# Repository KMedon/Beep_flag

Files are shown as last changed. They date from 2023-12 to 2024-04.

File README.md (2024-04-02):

# Football Referee Flags with LoRa Communication
# Overview
This repository houses my engineering project, a cutting-edge set of football referee flags designed with LoRa technology for seamless and effective wireless communication. Aimed at transforming the communication dynamics for referees, especially in lower leagues where advanced communication tools may not be readily available, this project seeks to enhance decision-making accuracy and efficiency on the field.

# Genesis
The inspiration behind this project was to bridge the communication gap faced by referees in lower-tier football leagues. These leagues often lack the resources for sophisticated communication devices, impacting the referees' ability to make quick and accurate decisions. By developing a reliable and easy-to-use set of referee flags with a receiver, this project aims to provide a cost-effective solution that elevates the quality of game officiating across all levels of play.

# Technology
Utilizing LoRa (Long Range) technology at the 868 MHz frequency enables dependable wireless communication over considerable distances. The core of this system is the RAK3172 module, powered by an STM32WLE5 microcontroller, chosen for its performance and reliability. The project was developed in STM32CubeIDE, incorporating the Sub-GHz PHY library for managing wireless communications efficiently.

# Mechanical Design and Testing
The project extends beyond software and communication technologies to include detailed mechanical design and rigorous testing. Files outlining the mechanical construction and assembly of both the flags and the receiver are provided, alongside results from tests designed to evaluate current consumption and the communication range, ensuring system efficiency and field readiness.

# PCB Design
A pivotal aspect of the project is the meticulously designed PCBs for the flag and receiver units. These designs prioritize low power consumption and effective LoRa communication, with durability and component reliability being key considerations to withstand the physical demands of football matches.





# Software
A standout feature of the software is the intuitive interaction between the referee flags and the receiver. When a referee presses the button on a flag, it triggers a buzzer on the receiver unit. This immediate audio feedback ensures that messages are conveyed promptly and unmistakably, supporting referees in maintaining focus on the game without distractions.




The software is crafted with attention to efficiency and responsiveness, ensuring seamless communication between devices. 

# Features
Long-range LoRa communication (868 MHz) tailored for referees in lower leagues
Custom PCB designs for flag and receiver, emphasizing efficiency and durability
In-depth mechanical designs with extensive durability and performance testing
Immediate audio feedback via receiver buzzer upon flag button press
Developed in STM32CubeIDE using the Sub-GHz PHY library

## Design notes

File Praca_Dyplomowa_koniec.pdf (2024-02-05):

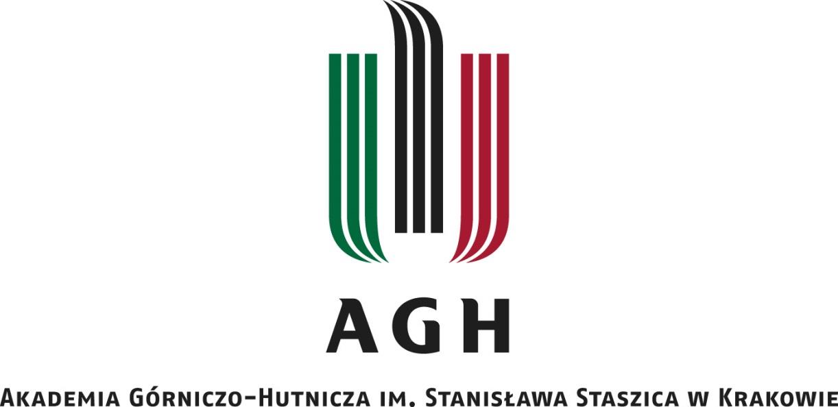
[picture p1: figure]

WYDZIAŁ INFORMATYKI, ELEKTRONIKI I TELEKOMUNIKACJI

INSTYTUT ELEKTRONIKI

PROJEKT DYPLOMOWY

## Elektroniczna flaga sędziowska

### Electronic referee flag

Autor: | Jakub Medoń
Kierunek studiów: | Elektronika i Telekomunikacja
Opiekun pracy: | dr inż. Łukasz Krzak

Kraków, 2024

## Spis treści

## 1. Wstęp

W dobie cyfryzacji, świat sportu przechodzi transformację, w której technologia zyskuje na

znaczeniu jako kluczowy element zapewniający sprawiedliwość i dynamikę rozgrywek.

Sędziowie sportowi pełnią kluczową rolę w pilnowaniu przestrzegania przepisów gry i

wymagane jest, aby podejmowane przez nich decyzje były szybkie i skuteczne. Komunikacja

pomiędzy członkami zespołu sędziowskiego jest niezbędna. Poprzez rozwój technologii

bezprzewodowej, sędzia piłkarski w trakcie spotkania ma do dyspozycji komunikację głosową

poprzez zestaw słuchawkowy, a także cichą komunikację za pomocą chorągiewki. Niniejsza

praca skupia się na projekcie oraz implementacji elektronicznej flagi sędziowskiej.

Motywacją do zrobienia tego projektu, była obserwacja, że sędziowie z niższych szczebli

rozgrywkowych nie stosują tego rodzaju komunikacji. Powodem tego jest zbyt wysoka cena

elektronicznych chorągiewek na rynku. Będąc świadomym jak dużą rolę odgrywa ten produkt

w podejmowaniu prawidłowych decyzji, postanowiono zaprojektować urządzenie, które będzie

spełniać tą samą funkcjonalność oraz będzie dostępne cenowo dla szerszego grona sędziów.

Celem pracy było zaprojektowanie i wykonanie prototypu elektronicznych flag

sędziowskich wraz z odbiornikiem, które komunikują się między sobą za pomocą technologii

LoRa. Głównym założeniem jest umożliwienie cichej i niezawodnej komunikacji w zespole

sędziowskim tak, aby po naciśnięciu przycisku na chorągiewce, sędzia główny otrzymywał

sygnał dźwiękowy bezpośrednio na swoje ramię.

Rozdział drugi przedstawia analizę rynku elektronicznych flag sędziowskich, ich

funkcjonalności oraz relację jakości do ceny. Następnie, w rozdziale trzecim, omówione zostały

technologie i narzędzia wykorzystane w projekcie, w tym technologia LoRa oraz

oprogramowanie wspomagające projektowanie i programowanie urządzeń.

W rozdziale czwartym szczegółowo opisano projekt płyty drukowanej (PCB), która stanowi

fundament dla elektronicznych komponentów opracowanego urządzenia, wraz z analizą celów

projektowych, metodologią opracowania schematów i rozmieszczenia elementów, a także

kryteriami doboru poszczególnych części. Następnie, rozdział piąty koncentruje się na procesie tworzenia oprogramowania, kluczowym dla funkcjonowania systemu, przedstawiając wybrane

biblioteki, sterowniki oraz implementację komunikacji bezprzewodowej.

W końcowej części pracy przedstawione zostały wyniki testów funkcjonalnych, zasięgu

oraz zużycia prądu, które posłużyły do wyciągnięcia wniosków i oceny wykonanego

prototypu. Całość zakończona jest podsumowaniem, które integruje wszystkie elementy

projektu, prezentując konkluzje i możliwe kierunki dalszego rozwoju.

## 2. Analiza istniejących rozwiązań

Opis ogólny

Współczesny rynek sprzętu sędziowskiego w sporcie charakteryzuje się ciągłym postępem

technologicznym, którego celem jest usprawnienie komunikacji na boisku oraz zwiększenie

precyzji podejmowanych decyzji. W ramach tego rozwoju, szczególne miejsce zajmują

elektroniczne flagi sędziowskie, które są kluczowym narzędziem w profesjonalnych

dyscyplinach sportowych takich jak piłka nożna i rugby. Te innowacyjne urządzenia zostały

zaprojektowane, aby zapewnić sędziom liniowym możliwość bezbłędnego i natychmiastowego

komunikowania się z sędzią głównym, nawet w najbardziej hałaśliwych i dynamicznych

warunkach meczowych.

Elektroniczne flagi sędziowskie wykorzystują różnorodne technologie komunikacyjne, w

tym systemy radiowe i dźwiękowe. Wśród dostępnych na rynku produktów wyróżniają się

modele, które oferują funkcje takie jak sygnalizacja dźwiękowa o różnych poziomach

głośności, wibracje, wskaźniki LED informujące o stanie naładowania baterii, ergonomiczny

kształt i odporność na warunki atmosferyczne.

Produkty na rynku różnią się pod względem specyfikacji, funkcjonalności i ceny, co

odzwierciedla różnorodne potrzeby użytkowników oraz dynamiczny rozwój. W tym rozdziale

przestawiona zostanie analiza najbardziej znaczących produktów na rynku.

Przegląd produktów

SignalBip Electronic Flags: To nowoczesne flagi sędziowskie charakteryzujące się

ergonomicznymi uchwytami, wykonane zostały z miękkiego materiału dla lepszego chwytu.

Zawierają również wskaźnik LED, który sygnalizuje stan naładowania baterii, a ich średni czas

ładowania wynosi godzinę, co jest akceptowalnym czasem umożliwiającym szybkie

przygotowanie sprzętu do użytku. System wykorzystuje pasmo częstotliwości od 863 do 870

MHz, co zapewnia niezawodność transmisji danych w warunkach typowych dla środowiska

stadionu piłkarskiego. SignalBip oferuje trzy poziomy głośności dźwięku i pięć poziomów

wibracji, co pozwala sędziemu dostosować urządzenie do własnych preferencji. W skład

zestawu wchodzą dwie flagi oraz opaska na ramię z sygnałem wibracyjnym i dźwiękowym dla

sędziego głównego [1].

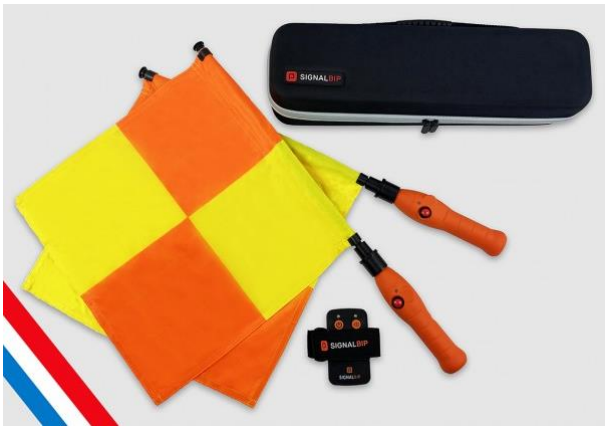
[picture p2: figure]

Rys. 1 Zestaw flag SignalBip [1]

ErvoCom Referee Flags: Używane w najwyższych ligach piłkarskich, w tym w Premier

League, Bundeslidze i podczas meczów FIFA. Flagi ErvoCom wyróżniają się zaawansowaną

technologią kodowania, która eliminuje ryzyko zakłóceń. Posiadają gumowane uchwyty, które

dobrze sprawdzają się na mokre i wilgotne warunki, a także szybko rozpoznawalne przyciski

na przedniej i tylnej części flagi. Flaga ErvoCom wibruje, aby potwierdzić wysłanie sygnału

do sędziego, posiada różne tryby wibracji dla pierwszego i drugiego asystenta sędziego.

Ponadto, urządzenie oferuje regulowaną głośność dźwięku, a jednostka odbiorcza sędziego

może być programowana do powiadamiania dźwiękiem, wibracją lub oboma bodźcami

jednocześnie [2].

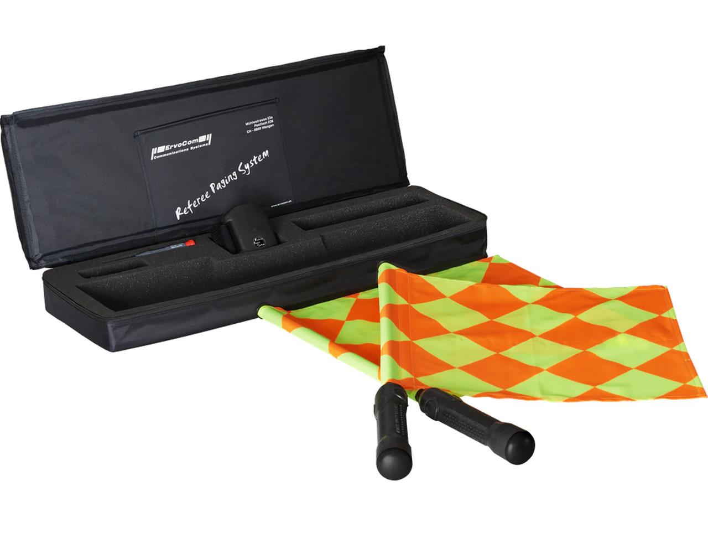
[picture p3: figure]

Rys. 2 Zestaw flag ErvoCom [2]

Analiza techniczna

W tab. 1 porównano specyfikacje techniczne dwóch czołowych modeli elektronicznych flag

sędziowskich: SignalBip Electronic Flags i ErvoCom Referee Flags.

Tab. 1 Porównanie specyfikacji technicznych wybranych produktów

Model | SignalBip Electronic Flags | ErvoCom Referee Flags
Cena | €579.80 | €729.95
Częstotliwość (MHz) | 863-870 | Nie ustalono
Komunikacja | Nie podano | Dwukierunkowa z potwierdzeniem odbioru
Maksymalna liczba flag | 5 flag na system | 10 flag na system
Funkcje powiadomień | Dźwięk (3 poziomy), wibracje (5 poziomów) | Dźwięk (3 poziomy), wibracje (5 poziomów)
Wodoodporność | Tak | Tak
Tryb oszczędzania energii | Tak | Tak
Wskaźnik baterii | LED | LED, Wibracja
Uchwyt | Uchwyty ergonomiczne | Uchwyty ergonomiczne
Materiał | Soft-touch | Nie podano

W obu przypadkach, produkty spełniają podobną funkcję – umożliwiają efektywną

komunikację między sędziami. Wybór między nimi zależy od indywidualnych potrzeb i

budżetu, przy czym ErvoCom oferuje większą skalowalność i zaawansowaną komunikację,

podczas gdy SignalBip jest bardziej dostępny cenowo.

## 3. Zastosowane technologie i oprogramowania

## 3.1. Technologia LoRa

Wprowadzenie

LoRa (ang. Long Range) to technologia komunikacji radiowej oferująca relatywnie daleki

zasięg, która wykorzystuje modulację rozpraszania widma opartą na CSS (ang. Chirp Spread

Spectrum). Umożliwia ona transmisję radiową na dużych dystansach przy jednoczesnym

niskim zużyciu energii. Dzięki temu, urządzenia IoT (ang. Internet of Things) w niektórych

aplikacjach mogą komunikować się przez lata bez konieczności wymiany baterii, co otwiera

nowe możliwości w dziedzinie zdalnego monitorowania i kontrolowania.

Historia LoRa sięga początków XXI wieku, kiedy to francuska firma Cycleo z Grenoble

opracowała i opatentowała tę technikę. Została ona później nabyta i spopularyzowana przez

korporację Semtech, przez co szybko stała się kluczowym elementem ekosystemu IoT. Dzięki

współpracy z założycielami Cycleo, Semtech dopracował technologię i wypuścił na rynek

dedykowane chipy, które znalazły zastosowanie w milionach urządzeń na całym świecie [3].

LoRa wykorzystywana jest w wielu dziedzinach, od inteligentnych miast, które monitorują

jakość powietrza, ruch uliczny i zarządzanie oświetleniem, po zaawansowane rolnictwo, gdzie

wykorzystuje się czujniki do optymalizacji zużycia wody i monitorowania warunków upraw.

Jest również kluczowa w zarządzaniu zasobami, takimi jak śledzenie przesyłek w logistyce i

monitorowanie stanu infrastruktury. Dzięki swojej adaptowalności, LoRa jest używana także

w inteligentnym zarządzaniu energią i w aplikacjach monitorowania dzikiej przyrody [4].

Zaletą tej technologii jest odporność na interferencje i zdolność do penetracji przeszkód, co

czyni ją idealną do zastosowań miejskich. Wadami są ograniczona przepustowość i wyższe

opóźnienia w transmisji danych, co sprawia, że nie nadaje się do aplikacji wymagających

szybkiego przesyłania dużej ilości danych, takich jak transmisja wideo czy komunikacja

głosowa w czasie rzeczywistym [4].

Modulacja

Technologia LoRa odnosi się do zasad twierdzenia Shannona-Hartleya, podkreślając, jak

krytyczne jest zarządzanie pasmem i stosunkiem sygnału do szumu (SNR ang. Signal-to-Noise

Ratio) dla maksymalizacji przepustowości kanału komunikacyjnego. W praktyce, LoRa

dostosowuje te parametry, aby umożliwić niezawodną transmisję danych w środowisku o

ograniczonej szerokości pasma oraz zmiennym SNR, co jest istotne dla zachowania spójności

i jakości komunikacji w systemie LoRa [5].

Kluczową techniką modulacji stosowaną w LoRa jest CSS, która jest specyficzną odmianą

modulacji częstotliwości sygnału radiowego. Chirp (ang. Compressed High Intensity Radar

Pulse) to sygnał, którego częstotliwość zmienia się liniowo w czasie, może rosnąć lub maleć.

Chirp pełni funkcję nośnika danych, co przekłada się na dobrą czułość odbiornika i odporność

na zakłócenia [5].

Kluczowe parametry modulacji:

1. Szerokość pasma (ang. Modulation Bandwidth): W LoRa, BW waha się od 125 kHz

do 500 kHz, co wpływa na szybkość transmisji danych i zasięg. Mniejsza szerokość

pasma pozwala na większy zasięg przy niższej szybkości.

2. Czynnik rozpraszania (ang. Spread Factor): SF w LoRa określa stopień rozpraszania

widma sygnału, z wartościami od 7 do 12. Wyższe wartości SF umożliwiają większy

zasięg transmisji, lecz przy niższej szybkości.

3. Wskaźnik kodowania (ang. Code Rate): CR odnosi się do redundantności w

kodowaniu FEC, pomagając korygować błędy transmisji. Wyższa redundancja

zwiększa niezawodność, ale zmniejsza przepustowość. Możliwe są 4 wartości tego

parametru: 4/5, 4/6, 4/7, 4/8 [6].

Szybkość bitową łącza można wyliczyć ze wzoru:

Rb = SF ∗

CR ∗ BW [Hz]
2

SF

Pasma częstotliwości

LoRa wykorzystuje pasma częstotliwości ISM (ang. Industrial, Scientific, Medical), które

są specyficzne dla danego regionu i nie wymagają licencji, na przykład 434/868 MHz w

Europie i 915 MHz w Ameryce Północnej. Wybór odpowiedniego pasma częstotliwości jest

kluczowy dla zapewnienia efektywnej komunikacji i długiego zasięgu, a także minimalizacji

zakłóceń i interferencji.

Tab. 2 Zakres pasma częstotliwości pracy LoRa w zależności od regionu

Region | Częstotliwość (MHz)
Europa | EU863-870, EU433
Chiny | CN470
Ameryka Północna | US915
Azja | AS923, AS920
Australia | AU915
Korea | KR920
Indie | IN865

Parametry jakości sygnału

Stosunek Sygnału do Szumu (SNR) w LoRa to kluczowy wskaźnik, który mierzy relację

między mocą odbieranego sygnału, a poziomem szumu na wejściu odbiornika radiowego. Jest

to krytyczna miara dla oceny jakości sygnału w systemach komunikacji bezprzewodowej.

Wysoki SNR wskazuje, że sygnał jest znacznie silniejszy niż szum, co prowadzi do mniejszej

liczby błędów i ponownych transmisji. W środowiskach o wysokim poziomie zakłóceń,

utrzymanie odpowiedniego SNR może być wyzwaniem, jednak LoRa jest zaprojektowana do

skutecznego działania nawet w trudnych warunkach, gdzie wartość parametru może być niska.

SNR ma bezpośredni wpływ na zasięg sygnału – wyższe wartości pozwalają na komunikację

na większe odległości i zapewniają lepszą jakość sygnału. W LoRa stosuje się różne techniki

do poprawy SNR, w tym wybór odpowiednich pasm częstotliwości, regulację mocy nadawania

i optymalizację anten, co ma na celu zwiększenie mocy sygnału lub zmniejszenie wpływu

szumu. Również parametry modulacji, takie jak szerokość pasma i czynnik rozpraszania, są

dostosowywane w zależności od warunków transmisji, tak aby zoptymalizować wartość parametru. Typowe wartości SNR dla LoRa mieszczą się w zakresie od -20dB do +10dB.

Wartość bliższa +10dB oznacza, że odbierany sygnał jest mniej zakłócony [7].

Wskaźnik Siły Odbieranego Sygnału (RSSI, ang. Received Signal Strength Indication)

jest niezwykle ważny dla oceny jakości i efektywności komunikacji w sieciach

bezprzewodowych. W technologii LoRa, RSSI mierzy rzeczywistą moc sygnału odbieranego

przez urządzenie i jest wyrażony w decybel-miliwatach (dBm). Wartości RSSI dają

bezpośrednią informację o sile sygnału w danej lokalizacji, co jest kluczowe dla ustalenia

zasięgu i niezawodności sieci LoRa. W środowiskach o zmiennym poziomie zakłóceń, wysokie

wartości RSSI wskazują na silny sygnał, co przekłada się na stabilniejszą transmisję danych.

W LoRa, monitoring i optymalizacja RSSI są niezbędne do zarządzania siecią, ponieważ

pozwalają na dostosowanie ustawień, takich jak czynnik rozpraszania i szerokość pasma, do

warunków środowiskowych. Optymalizacja RSSI jest istotna dla zapewnienia efektywnej

komunikacji i minimalizacji zakłóceń, co ma bezpośredni wpływ na jakość i skuteczność

systemu LoRa. Typowe wartości RSSI dla LoRa mieszczą się w zakresie od -120dBm do -

30dBm. Wartość bliższa -30dBm oznacza, że odebrany sygnał jest silniejszy [7].

## 3.2. Wykorzystane oprogramowania i narzędzia

KiCAD

KiCAD został wykorzystany do zaprojektowania schematów elektronicznych i płytek

drukowanych (PCB, ang. Printed Circuit Board) dla systemu elektronicznych flag

sędziowskich. Jako zaawansowane, darmowe i otwarte oprogramowanie CAD, KiCAD

umożliwił precyzyjne zaplanowanie układów elektronicznych, co było niezbędne dla

zapewnienia efektywnej komunikacji i stabilności systemu.

Dzięki KiCAD możliwe było tworzenie szczegółowych schematów elektronicznych, co

ułatwiło identyfikację potencjalnych problemów projektowych na wczesnym etapie. W fazie

projektowania płytek drukowanych, KiCAD zapewnił elastyczne narzędzie do efektywnego

rozmieszczania komponentów i trasowania połączeń. Jego interfejs użytkownika i bogate

biblioteki komponentów znacząco przyspieszyły proces projektowania.

Zastosowano również funkcje kontroli błędów i narzędzia do wizualizacji 3D, co pozwoliło

na dokładne sprawdzenie projektu przed przystąpieniem do fazy produkcyjnej. Pozwoliło to

zminimalizować ryzyko popełnienia kosztownych błędów i umożliwiło optymalizację projektu

pod względem wydajności oraz kosztów produkcji

STM32CubeIDE

STM32CubeIDE, jako zintegrowane środowisko programistyczne, odegrało kluczową rolę

w rozwoju oprogramowania dla projektu. To narzędzie umożliwiło skuteczne programowanie

i debugowanie oprogramowania sterującego modułami RAK3172. Wyposażone w

zaawansowane funkcje wspierające różne języki programowania i zintegrowane narzędzia do

debugowania, STM32CubeIDE znacząco przyczyniło się do efektywnego tworzenia systemu.

Dzięki możliwości dokładnego śledzenia działania oprogramowania, STM32CubeIDE

pozwoliło na szybką identyfikację i rozwiązywanie problemów, co zwiększyło niezawodność i

wydajność finalnego produktu. Narzędzie to okazało się być nieocenionym elementem w

procesie opracowywania oprogramowania do systemu elektronicznych flag sędziowskich.

GPS Fields Area Measure

W ramach przeprowadzanych badań nad zasięgiem komunikacji LoRa z wykorzystaniem

modułów RAK3172, skorzystano z aplikacji mobilnej "GPS Fields Area Measure" do

dokładnego ustalenia odległości między urządzeniami. Aplikacja ta, wykorzystując system

GPS, pozwoliła na precyzyjne zmierzenie i zarejestrowanie odległości pomiędzy

poszczególnymi punktami testowymi.

Testy przeprowadzono na otwartej przestrzeni, gdzie dokładne wyznaczenie odległości

między modułami było kluczowe dla wiarygodności pomiarów zasięgu. "GPS Fields Area

Measure" umożliwiła łatwe i szybkie mierzenie odległości, co znacząco usprawniło proces

testowania. Dzięki tej aplikacji efektywnie udokumentowano wszystkie wykonane pomiary.

STLink-V3MINIE

Programator STLink-V3Minie został użyty do zaprogramowania modułów RAK3172 w

projekcie. Dzięki złączu SWD (ang. Serial Wire Debug), programowanie modułów przeprowadzono w sposób efektywny, co było kluczowe dla prawidłowego działania systemu

LoRa. Programator ten, ze względu na swoją wydajność i niezawodność, był idealnym

narzędziem do tego zadania.

Dodatkowo, wykorzystanie interfejsu UART (ang. Universal Asynchronous Receiver and

Transmitter) w STLink-V3Mini umożliwiło śledzenie komunikacji między modułami. Dzięki

temu można było monitorować i diagnozować działanie systemu w czasie rzeczywistym, co

znacząco ułatwiło proces debugowania i testowania. Ta integracja narzędzi programistycznych

była istotna dla zapewnienia wysokiej jakości i stabilności finalnego produktu.

Rys. 3 STLINK-V3MINIE [8]

Lutownica Reball 72W

W projekcie wykorzystano lutownicę model Reball 72W, która odegrała kluczową rolę w

montażu i naprawie komponentów elektronicznych. Dzięki jej wysokiej mocy i precyzji,

możliwe było dokładne i efektywne łączenie elementów układów elektronicznych. Użycie tego

modelu lutownicy zapewniło nie tylko wysoką jakość lutowanych połączeń, ale również

przyczyniło się do zwiększenia niezawodności i funkcjonalności całego systemu. Umiejętne wykorzystanie lutownicy Reball 72W miało istotny wpływ na skuteczność procesu montażu

modułów oraz innych składników elektronicznych w ramach projektu.

## 3.3. Wybór sprzętu i komponentów

Moduł RAK3172

Moduł RAK3172 WisDuo, oparty na chipie STM32WLE5CC, został wykorzystany w

projekcie jako urządzenie transmisyjno-odbiorcze o zredukowanym zużyciu energii. Ten

moduł oferuje łatwe w użyciu, kompaktowe i energooszczędne rozwiązanie dla aplikacji

bezprzewodowej transmisji danych. Dodatkowo, wspiera komunikację LoRa P2P (ang. Point-

to-Point), co pozwoliło na szybką implementację spersonalizowanej sieci LoRa.

RAK3172 charakteryzuje się dalekim zasięgiem transmisji, przekraczającym 15 km przy

optymalnej antenie oraz wydajnym procesorem ARM Cortex-M4 32-bit. Posiada 256 KB

pamięci flash z ECC (ang. Error Checking and Correction) i 64 KB pamięci RAM (ang.

Random-access memory). Jego ultra-niskie zużycie energii, wynoszące zaledwie 1.69 µA w

trybie uśpienia, czyni go idealnym do zastosowań zasilanych bateryjnie [9].

Małe rozmiary modułu RAK3172 (15x15.5 mm) były kluczowe dla jego zastosowania w

projekcie, ponieważ umożliwiły łatwe zintegrowanie go z obudową chorągiewki, nie

ograniczając jej funkcjonalności ani estetyki. Wybór tego modułu przyczynił się do

efektywności i elastyczności całego systemu, co było niezbędne do realizacji celów projektu.

Antena

W projekcie wykorzystano antenę TI.08.C.0111 firmy Taoglas, przeznaczoną do pasma ISM

868 MHz, co jest istotne dla aplikacji LoRa. Zakres temperatury pracy anteny wynosił od -40°C

do 85°C, co wskazuje na jej odporność na różnorodne warunki środowiskowe i umożliwia jej

wykorzystanie w szerokim zakresie aplikacji [10].

Wybór anteny TI.08.C.0111 był podyktowany potrzebą zapewnienia optymalnego zasięgu i

jakości sygnału w systemie LoRa, przy jednoczesnym zachowaniu kompaktowych wymiarów

i niskiego profilu, co miało kluczowe znaczenie dla integracji anteny z projektem.

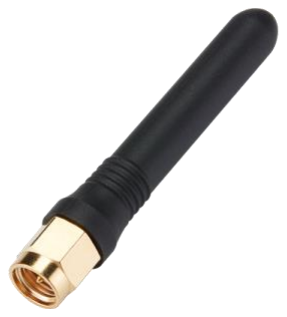
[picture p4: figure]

Rys. 4 Antena TI.08.C.0111 [10]

Rękojeść chorągiewki

W projekcie wykorzystano ergonomiczne rękojeści firmy SignalBip. Rękojeści wyposażono

w przycisk, który jest kluczowy dla funkcjonalności projektu. Posiada również specjalne

miejsce na zamontowanie płytki PCB, co umożliwiło integrację bez konieczności

wprowadzania zmian projektowych. Istotną modyfikacją była adaptacja wewnętrznej struktury

chorągiewki w celu umieszczenia specjalnego koszyczka na dwie baterie typu AAA.

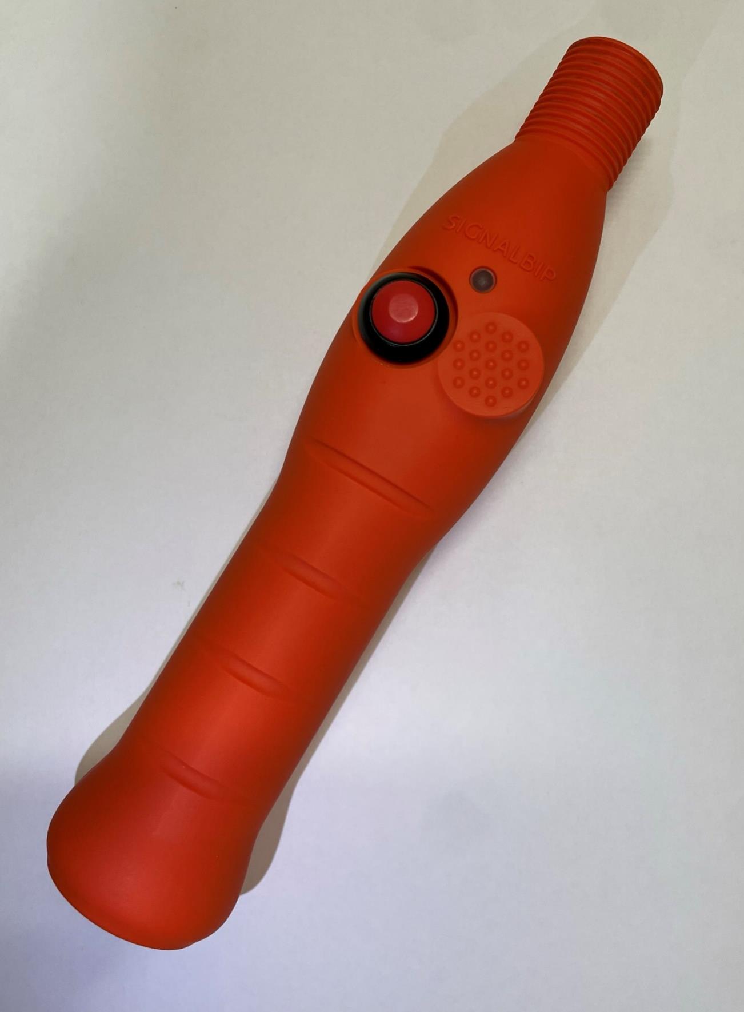
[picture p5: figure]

Rys. 5 Rękojeść chorągiewki sędziego asystenta

Obudowa odbiornika

W ramach projektu odbiornika na ramię sędziego, wybrano obudowę Maszczyk KM-79A

ABS o wymiarach 101 x 81 x 31 mm. Jest to dwuczęściowa, uniwersalna obudowa wykonana

z materiału ABS (ang. Acrylonitrile Butadiene Styrene), która charakteryzuje się wysoką

trwałością oraz odpornością na różnorodne warunki eksploatacyjne.

Kluczowym czynnikiem, który przesądził o wyborze tej obudowy jest jej funkcjonalność.

Przy wymiarach zewnętrznych 101 x 81 x 31 mm, obudowa oferuje wystarczającą przestrzeń

do umieszczenia niezbędnych komponentów elektronicznych. Obudowa jest łączona za

pomocą śrubek, co ułatwia montaż i demontaż, umożliwiając łatwy dostęp do peryferii systemu

odbiornika. Wspomniany dostęp jest również korzystny z punktu widzenia stabilności, co jest

istotne w kontekście potencjalnych przyszłych modyfikacji projektu [11].

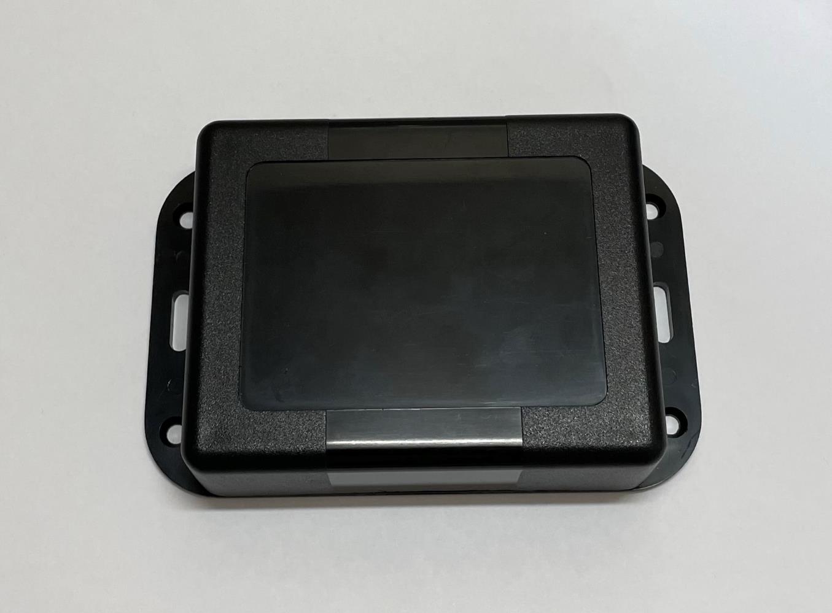
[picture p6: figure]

Rys. 6 Obudowa odbiornika sędziego głównego

## 4. Opis projektu PCB

## 4.1. Wstęp oraz cel projektu

W ramach pracy inżynierskiej, jednym z kluczowych zadań było zaprojektowanie

dedykowanych płytek drukowanych (PCB) dla nadajnika i odbiornika. Celem projektu PCB

dla nadajnika było osiągnięcie kompatybilności z rękojeścią, tak aby płytka mogła być łatwo

zintegrowana w jej wnętrzu. Istotnym wymaganiem było także zapewnienie możliwości

podłączenia przewodów do przycisku umieszczonego w rękojeści. W przypadku PCB

odbiornika, głównym celem było dopasowanie do jego specyficznej obudowy oraz

zaimplementowanie buzzer'a jako elementu sygnalizacyjnego.

Projektowanie PCB zostało przeprowadzone przy użyciu KiCAD, co umożliwiło

precyzyjne zaplanowanie układów elektronicznych, rozmieszczenie komponentów oraz

trasowanie ścieżek. KiCAD, jako zaawansowane oprogramowanie do projektowania PCB,

zapewniło niezbędne narzędzia do stworzenia efektywnych i niezawodnych rozwiązań,

spełniających wszystkie postawione wymagania projektowe.

## 4.2. Projekt nadajnika: schemat i funkcje elementów

Przegląd ogólny

Schemat przedstawia układ elektroniczny nadajnika, systemu elektronicznych flag

sędziowskich. Skupia się wokół modułu RAK3172, który połączony jest z różnymi peryferiami

i interfejsami. Układ zasilono napięciem 3V, co jest standardowe dla wielu mikrokontrolerów

o niskim zużyciu energii. Umieszczono także elementy do komunikacji szeregowej, wskaźniki

LED oraz przyciski do resetowania i wyboru trybu bootowania.

Opis użytych komponentów

- Moduł: Szczegółowy opis Modułu RAK3172 został wykonany w rozdziale 3.3.
- Kondensatory filtrujące (C1, C3, C8): Są to kondensatory odsprzęgające, które

stabilizują napięcie zasilania, redukując szumy i zapewniając oczyszczone zasilanie dla

obwodów cyfrowych i radiowych.

- Diody LED (D2, D3): Dwie diody LED oznaczone jako GREEN I RED, zostały

wykorzystane jako wskaźniki statusu, sygnalizujące różne stany pracy układu.

- Przyciski (RST, BOOT): Przyciski służące do resetowania modułu oraz do wejścia w

tryb bootloadera.

- Złącze (J5): Interfejs STDC14 umożliwił zaprogramowanie modułu.Jest kompatybilny

z programatorem STLink-v3minie. Piny SWDIO i SWCLK zostały podłączone do

odpowiednich pinów modułu. Komunikacja UART również została zrealizowana

poprzez podłączenie linii TX i RX między złączem, a modułem. Ważnym aspektem

było podłączenie linii VCC, które umożliwia debugerowi detekcję poziomu napięcia

układu. W pierwotnym projekcie pominięto podłączenie pinu RST ze złącza STDC14

do pinu resetu modułu. Brak tego połączenia uniemożliwiał wykorzystanie

zewnętrznego resetowania modułu za pomocą debugera, co jest kluczowe podczas

procesu programowania. Ta pomyłka została zidentyfikowana i poprawiona w

późniejszej fazie projektu.

- Rezystory: Rezystory R1/R2 pełnią funkcje ograniczenia prądu dla diod LED, wartości

rezystancji wyliczono za pomocą prawa Ohma. Element R3 jest rezystorem

podciągającym (ang. Pull-up Resistor), który utrzymuje pin resetu w stanie wysokim,

co zapobiega przypadkowemu resetowaniu urządzenia. Rezystory R4, R5, R7 i R8 to

elementy zabezpieczające przed odbiciami sygnałów (ang. Bouncing) i zakłóceniami

elektromagnetycznymi. Element R6 zapewnia utrzymanie stanu niskiego na pinie PA1,

który jest aktywnie sterowany.

- Punkt testowy (ang. TestPoint): Miejsce na schemacie, które umożliwia łatwe

przylutowanie przewodów od przycisku.

- Zasilanie: Układ został zasilony napięciem 3V poprzez dwie baterie AAA.

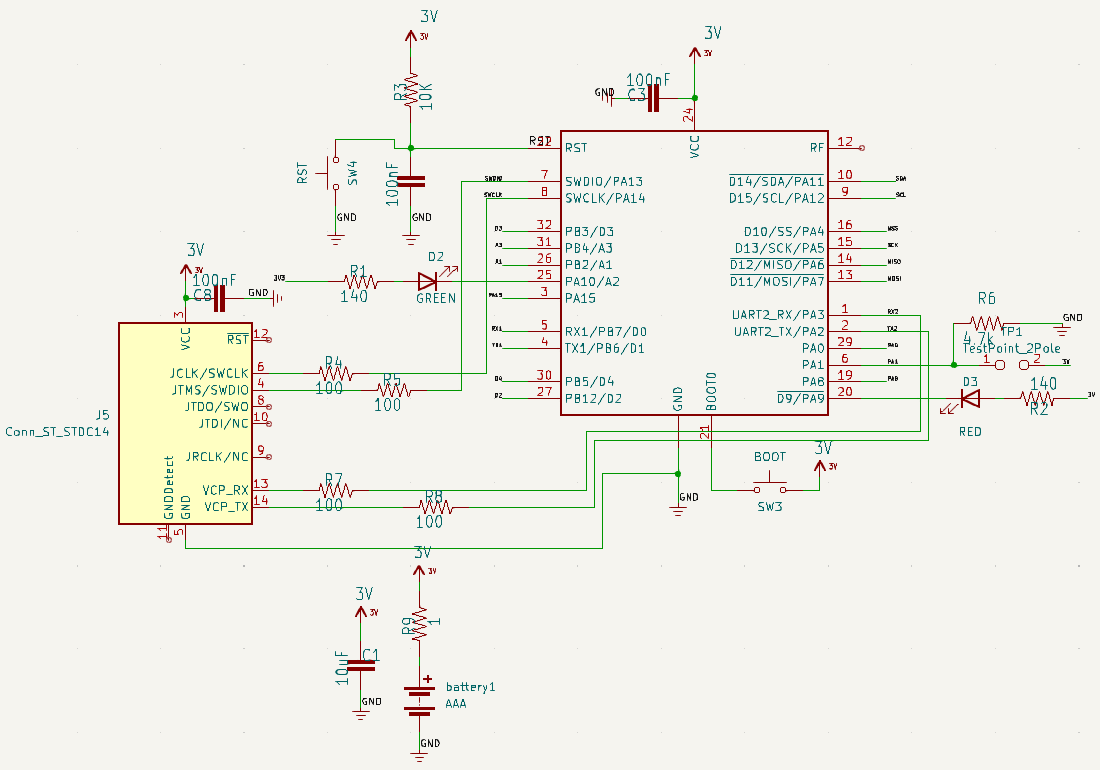
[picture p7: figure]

Rys. 7 Schemat elektroniczny nadajnika wykonany w programie KiCAD

Layout PCB

Projekt layoutu PCB dla nadajnika został dokładnie opracowany, aby spełnić wymagania

techniczne i ergonomiczne. Przyjęto ścieżki o szerokości 0.4 mm dla linii zasilających, co

zapewniało odpowiedni przekrój dla wymaganego prądu, natomiast ścieżki o szerokości 0.2

mm były przeznaczone do standardowych połączeń sygnałowych. Takie różnicowanie

szerokości ścieżek było istotne dla zachowania optymalnej pracy układu i minimalizacji

potencjalnych zakłóceń.

Moduł został strategicznie rozmieszczony po prawej stronie płytki, co wynikało z

konstrukcji rękojeści chorągiewki oraz potrzeby umieszczenia anteny w taki sposób, by była

skierowana ku górze chorągiewki. Taka lokalizacja modułu umożliwiała także efektywne

wykorzystanie przestrzeni na PCB.

Piny zasilania zostały umiejscowione po lewej stronie PCB, co odzwierciedlało położenie

koszyka z bateriami na dole chorągiewki. To rozwiązanie zapewniało skuteczny przepływ

energii od źródła zasilania do kluczowych komponentów układu.

Centralne położenie zielonej diody LED było uwarunkowane konstrukcją rękojeści

chorągiewki. Posiada ona tunel wizyjny, który przepuszcza światło zapalonej diody. Dzięki

temu, sygnalizacja pracy urządzenia jest klarowna i łatwo zauważalna przez użytkownika.

Ponadto, płytka posiada otwór montażowy o średnicy 2 mm, co umożliwiło solidne

przymocowanie PCB wewnątrz chorągiewki. Rozmiar PCB narzucał ograniczenia, które

wymagały racjonalnego wykorzystania dostępnej przestrzeni, szczególnie przy umieszczaniu

elementów i planowaniu ścieżek.

Na spodniej stronie PCB wykonano poligon masy, co jest standardową praktyką mającą na

celu poprawę odprowadzania ciepła oraz ochronę przed zakłóceniami elektromagnetycznymi.

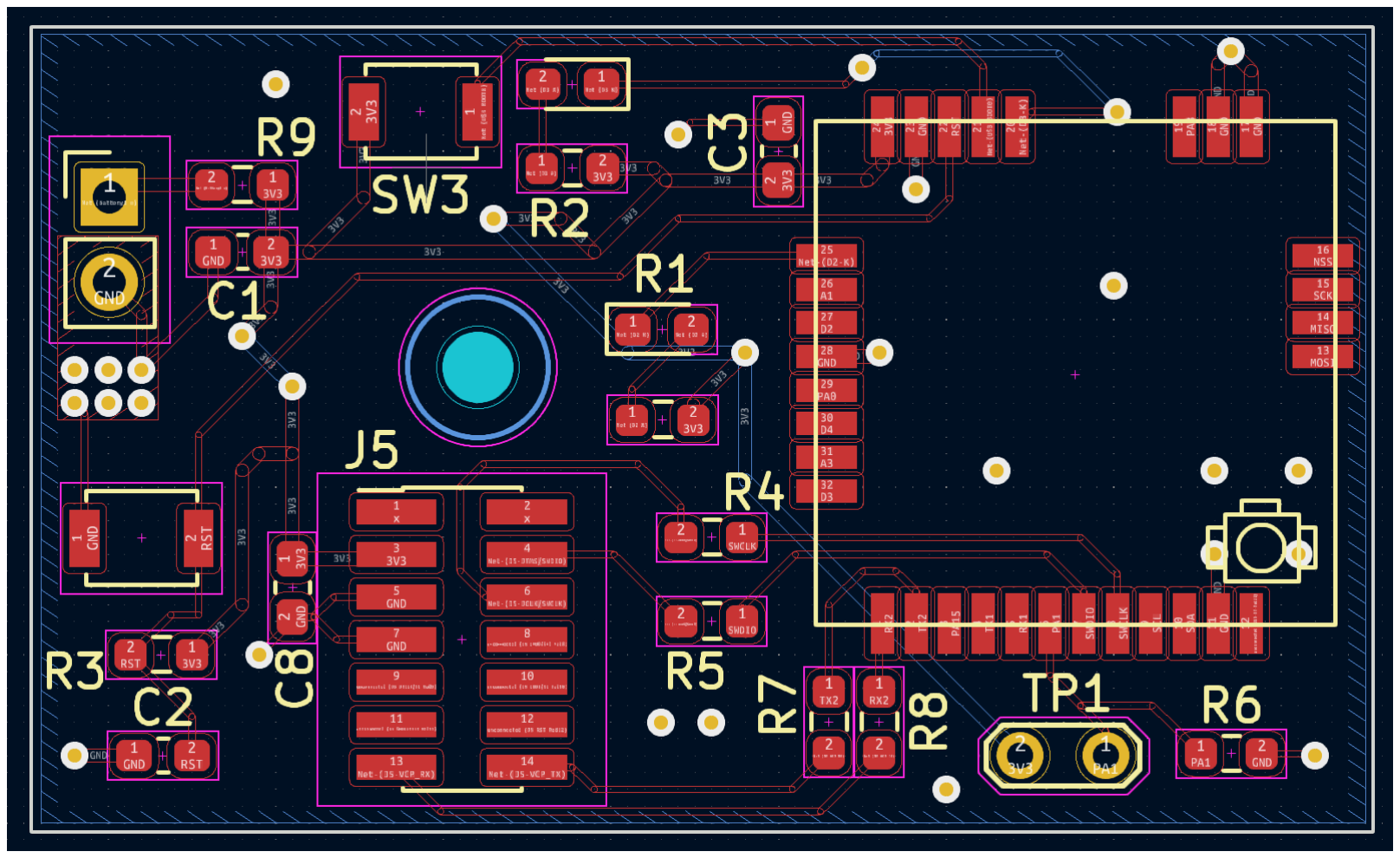
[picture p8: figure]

Rys. 8 Layout płytki PCB – nadajnika

Montaż elementów

Montaż składników na płytce drukowanej przeprowadzono ręcznie przy użyciu stacji

lutowniczej Reball 72W, co pozwoliło na precyzyjne umiejscowienie i lutowanie

komponentów. Po zakończeniu montażu, wykorzystując funkcję testowania ciągłości

multimetru, dokonano weryfikacji jakości połączeń lutowniczych, co jest kluczowe dla

zapewnienia niezawodności działania układu.

Problem z brakiem ścieżki sygnału reset (RST) ze złącza STDC14 do modułu RAK3172,

rozwiązano poprzez dodanie dodatkowego przewodu. Zapewniło to niezbędną funkcjonalność

resetowania modułu, co jest niezmiernie istotne podczas programowania i debugowania.

Podczas montażu płytki PCB zastosowano środki ostrożności mające na celu ochronę

delikatnych komponentów elektronicznych przed uszkodzeniem elektrostatycznym. Użyto

maty uziemiającej, aby zminimalizować ryzyko wyładowań elektrostatycznych, co jest

standardową procedurą w pracach lutowniczych.

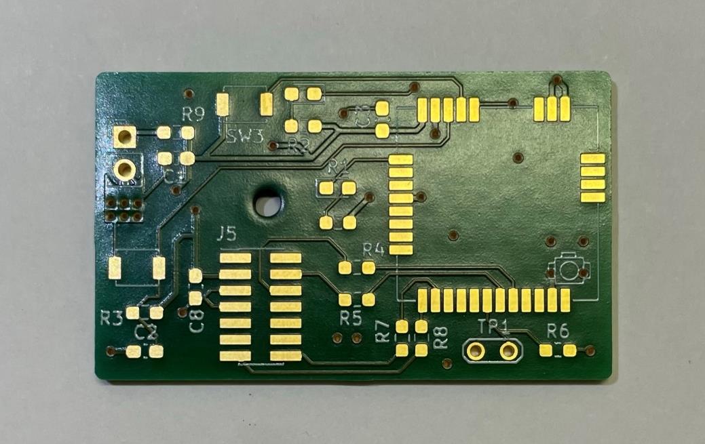
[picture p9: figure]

Rys. 9 Płytka PCB nadajnika przed montażem elementów

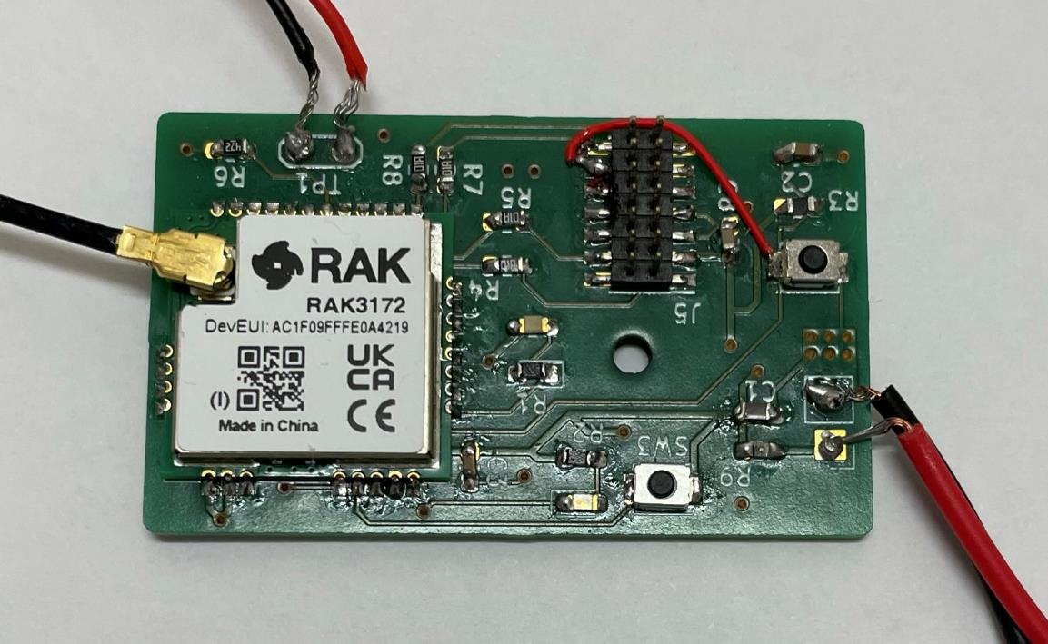
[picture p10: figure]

Rys. 10 Płytka PCB nadajnika po montażu

## 4.3. Projekt odbiornika: schemat i funkcje elementów

Przegląd ogólny

Montaż płytki PCB odbiornika był w dużej mierze analogiczny do procesu stosowanego

przy nadajniku. Większość użytych elementów oraz ogólny przebieg prac były podobne, co

pozwoliło na efektywne wykorzystanie doświadczeń zdobytych podczas montażu nadajnika.

Równolegle, zastosowano te same techniki lutowania oraz narzędzia, zapewniając spójność i

jakość wykonania.

Szczegółowy opis komponentów

- Buzzer: W konstrukcji odbiornika zastosowano piezoelektryczny buzzer AI-1203B-1P,

który służy do sygnalizacji dźwiękowej. Jego napięcie znamionowe to 3V, co spełnia

warunki projektu. Prąd znamionowy wynosi 30mA, a częstotliwość dźwięku to 2.3kHz.

- Tranzystor: W układzie zastosowano tranzystor bipolarny 2N3904BU, który pełni

funkcję sterowania buzzerem w odbiorniku. Wykorzystanie tego elementu było

konieczne, aby zapewnić wyższy prąd kolektora niezbędny do aktywacji buzzera.

- Rezystor (R6): Zadaniem rezystora jest zapewnienie odpowiedniego prądu bazy dla

tranzystora, który jest niezbędny do jego aktywacji i umożliwienia przepływu prądu

kolektora.

Pozostałe elementy w układzie są jednakowe jak w projekcie nadajnika [12] [13].

Obliczenie prądu bazy

IB =

IC
β

=

30mA
100

= 0.3mA,

gdzie: | IB − prąd bazy,

IC − prąd kolektora (prąd znamionowy buzzera),

β − wzmocnienie prądowe tranzystora.

Obliczenie wartości rezystora bazy

RB =

VCC−VBE
IB

=

3V−0.7V
0.3mA

= 7667Ω,

gdzie: | VCC – napięcie zasilania,

VBE − spadek napięcia na złączu baza-emiter,

IB − prąd bazy.

Rys. 11 Schemat elektroniczny odbiornika wykonany w programie KiCAD

Layout PCB

W projekcie layoutu PCB odbiornika zastosowano podobne zasady co w przypadku

nadajnika. Przyjęto ścieżki o szerokości 0.4 mm dla linii zasilających, natomiast ścieżki o

szerokości 0.2 mm były przeznaczone do standardowych połączeń sygnałowych.

Centralne umiejscowienie modułu RAK3172 na płytce PCB umożliwiło efektywne

rozprowadzenie ścieżek do wszystkich elementów zewnętrznych. Taka organizacja layoutu

sprzyjała prostocie montażu i minimalizacji długości połączeń. W projekcie uwzględniono dwa

otwory montażowe o średnicy 2mm, odpowiadające dwóm otworom w obudowie odbiornika.

Dzięki temu zabezpieczono mocowanie płytki w sposób umożliwiający łatwą instalację i

stabilne utrzymanie PCB w obudowie urządzenia.

Podobnie jak w nadajniku, na spodniej stronie PCB dodano poligon masy, co jest

standardową praktyką mającą na celu poprawę odprowadzania ciepła oraz ochronę przed

zakłóceniami elektromagnetycznymi.

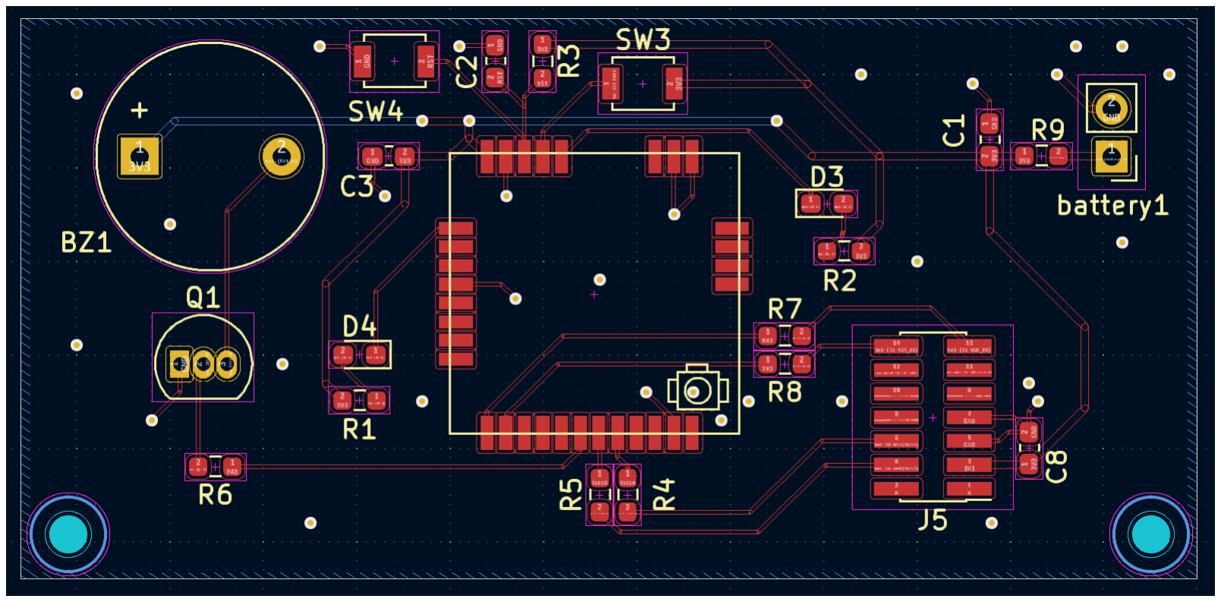
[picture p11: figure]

Rys. 12 Layout płytki PCB – odbiornika

Montaż elementów

Proces montażu PCB odbiornika został przeprowadzony z zachowaniem identycznych

procedur i technik, które zastosowano przy nadajniku. Użyto tej samej stacji lutowniczej Reball

72W, co zapewniło precyzję w umiejscowieniu i lutowaniu komponentów, a następnie

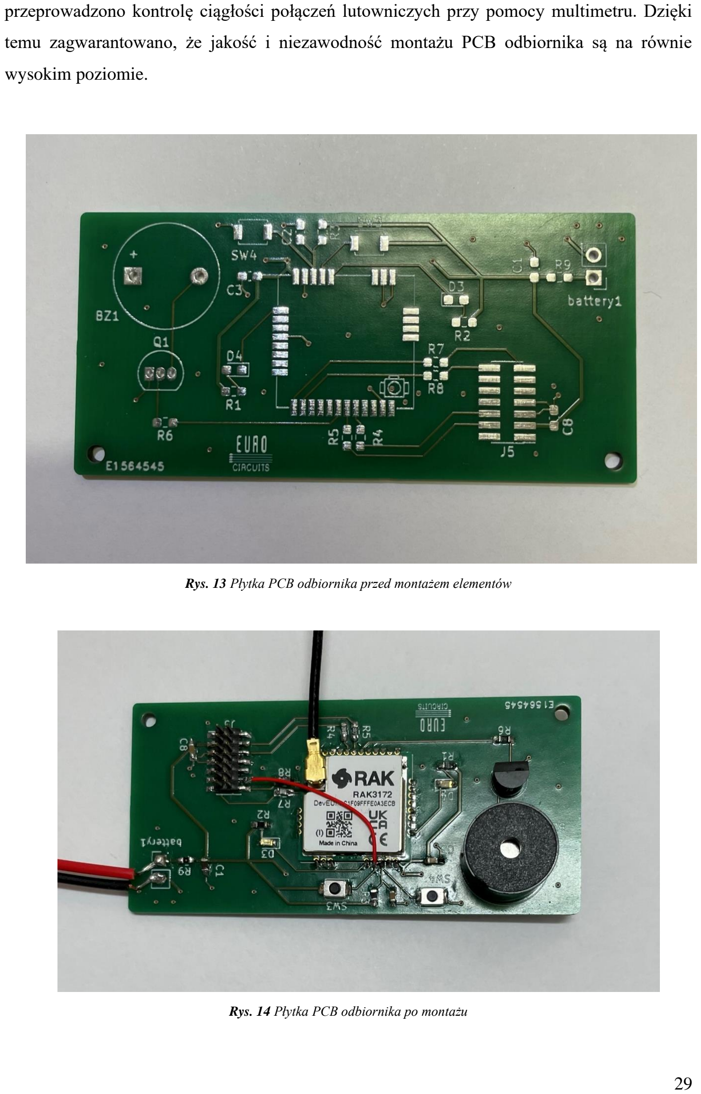
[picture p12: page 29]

przeprowadzono kontrolę ciągłości połączeń lutowniczych przy pomocy multimetru. Dzięki

temu zagwarantowano, że jakość i niezawodność montażu PCB odbiornika są na równie

wysokim poziomie.

Rys. 13 Płytka PCB odbiornika przed montażem elementów

Rys. 14 Płytka PCB odbiornika po montażu

## 5. Opis projektu oprogramowania

## 5.1. Wstęp oraz cel projektu

Rozdział ten poświęcony jest projektowi oprogramowania, które stanowi kluczowy element

systemu zapewniającego komunikację bezprzewodową pomiędzy chorągiewką a odbiornikiem.

Zastosowano środowisko STM32CubeIDE od STMicroelectronics, które wybrano ze względu

na swoją zaawansowaną funkcjonalność oraz integrację z mikrokontrolerami serii STM32.

Celem projektu oprogramowania było stworzenie niezawodnego mechanizmu komunikacji,

który pozwala na bezprzewodowe przesyłanie sygnałów. W tym przypadku, nadajnik,

zainstalowany w chorągiewce, ma za zadanie wysłać sygnał po aktywacji przez użytkownika,

czyli wciśnięciu przycisku. Odbiornik, po odebraniu sygnału, uruchamia buzzer, informując

użytkownika o zaistniałym zdarzeniu.

## 5.2. Wykorzystane biblioteki i sterowniki

### 5.2.1. STM32CubeWL

Pakiet zaprojektowany do obsługi modułów STM32WL z wbudowanym modułem LoRa,

oferuje szeroki zakres narzędzi i bibliotek umożliwiających efektywną pracę z radiem oraz

konfigurację innych funkcjonalności modułu [14].

STM32WLxx_HAL_Driver

Biblioteka HAL (ang. Hardware Abstraction Layer) jest integralną częścią pakietu

STM32CubeWL, zapewniając warstwę abstrakcji sprzętowej, co ułatwiło programowanie na

poziomie sprzętowym. Użycie HAL pozwoliło na łatwiejszą konfigurację peryferiów modułu

oraz obsługę różnych trybów pracy radia LoRa. Bibliotekę wykorzystano do inicjalizacji

modułów takich jak GPIO (ang. General-Purpose Input/Output), czy UART.

Middleware SubGHz_Phy

Oprogramowanie pośredniczące (ang. Middleware) odegrało centralną rolę w projekcie,

dostarczając niezbędnych funkcji i procedur do obsługi radiowego układu nadawczo-

odbiorczego. Biblioteka umożliwiła skonfigurowanie parametrów transmisji z modulacją

LoRa, takich jak częstotliwość, moc nadawania, szerokość pasma, czy format modulacji.

Użycie tego oprogramowania znacznie uprościło proces implementacji protokołu

komunikacyjnego.

CMSIS

„Standard CMSIS (Cortex Microcontroller Software Interface Standard) jest to uniwersalny

interfejs programowy, stworzony przez firmę ARM, który umożliwia komunikację z

peryferiami i rdzeniem Cortex za pomocą ustandaryzowanych funkcji i definicji. CMSIS

dostarcza mechanizmów do obsługi układów peryferyjnych, systemów operacyjnych czasu

rzeczywistego oraz aplikacji wykorzystujących interfejsy komunikacyjne: Ethernet, UART

oraz SPI” [15].

### 5.2.2. RAK3172_STM32CubeWL_SDK

SDK (ang. Software development kit) dla modułu RAK3172 w środowisku STM32CubeWL

dostarcza szczegółowych informacji na temat ustawień wymaganych do prawidłowej pracy

modułu. Skonfigurowano ustawienia w pliku .ioc, który jest integralną częścią środowiska

STM32Cube [16].

Kluczowe elementy konfiguracyjne

- GPIO: Konfiguracja pinów GPIO obejmuje ustawienie odpowiednich trybów

pracy (wejście, wyjście, alternatywna funkcja, analog).

- USART2: Ustawiono istototne parametry do osiągnięcia komunikacji pomiędzy

modułem, a komputerem. Skonfigurowano parametry prędkości transmisji,

bitów danych, bitów stopu i kontrolę parzystości. Tryb ustawiono na

asynchroniczny.

- RCC (ang. Reset and Clock Control): Konfiguracja kontrolera RCC ma na

celu zapewnienie odpowiednich źródeł zegara dla modułu. Skonfigurowano

HSE oraz LSE (ang. High/Low Speed Clock) jako „Crystal/Ceramic

Resonator”.

- RTC (ang. Real-Time Clock): Aktywacja RTC zapewnia dokładne

odmierzanie czasu w systemie. Skonfigurowano źródło zegara, kalendarz oraz

włączono alarm A.

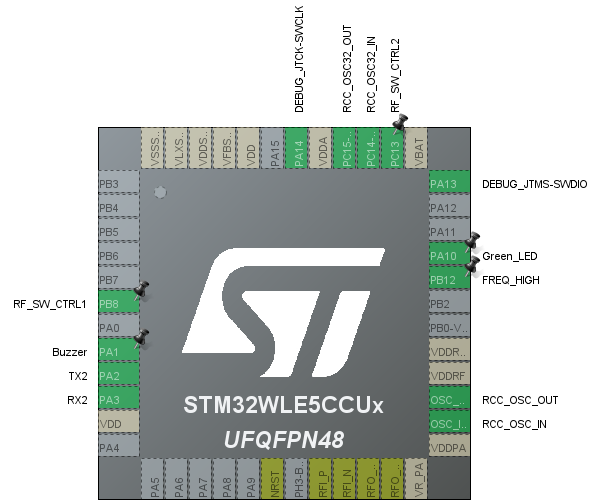
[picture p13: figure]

Rys. 15 Konfiguracja pinów w projekcie (odbiornik)

Oba urządzenia, nadajnik i odbiornik, wykorzystują te same konfiguracje dla kluczowych

modułów, takich jak USART2, RCC oraz RTC. Występuje różnica w konfiguracji pinu PA1 w

obu urządzeniach, która jest związana z ich specyficznymi funkcjami:

- W nadajniku, pin PA1 jest skonfigurowany jako GPIO Input, co pozwala na

podłączenie i obsługę przycisku.

- W odbiorniku, ten sam pin, PA1, jest skonfigurowany jako GPIO Output,

który steruje buzzerem.

## 5.3. Funkcjonalność oprogramowania

### 5.3.1. Implementacja komunikacji bezprzewodowej

W rozdziale 5.3.1. opisano proces implementacji komunikacji LoRa. Skonfigurowano pliki

subghz_phy_app.c oraz subghz_phy_app.h, które stanowią rdzeń zarządzania radiem.

W pliku subghz_phy_app.h ustawiono parametry konfiguracyjne modułu radiowego, które

były kluczowe dla określenia trybu pracy i specyfikacji sygnału. Proces składał się z

następujących etapów:

- Definicja trybu modemu: Zdefiniowano USE_MODEM_LORA, a następnie

ustawiono na 1, co oznaczało, że wybrano tryb pracy modemu LoRa.

- Ustawienie częstotliwości radiowej: Zdefiniowano RF_FREQUENCY na 868000000

Hz, co ustawiło częstotliwość pracy modułu na 868 MHz. Jest to typowa częstotliwość

dla komunikacji LoRa w Europie (kanał nr 17).

- Definicja mocy sygnału: Wartość TX_OUTPUT_POWER została zdefiniowana jako

14 dBm, co określa moc sygnału transmitowanego.

- Konfiguracja parametrów LoRa: W Tab. 3 pokazano parametry oraz ich wartości,

były one kluczowe dla konfiguracji charakterystyk sygnału LoRa, takich jak zasięg,

szybkość transmisji i odporność na zakłócenia.

Tab. 3 Konfiguracja parametrów LoRa w pliku subghz_phu_app.h

Parametr | Wartość
LORA_BANDWIDTH | 125 kHz
LORA_SPREADING_FACTOR | SF7
LORA_CODINGRATE | 4/5
LORA_PREAMBLE_LENGTH | 8
LORA_SYMBOL_TIMEOUT | 5
LORA_FIX_LENGTH_PAYLOAD_ON | False
LORA_IQ_INVERSION_ON | False

Na rys.16 przedstawiono proces inicjalizacji modułu radiowego w pliku subghz_phy_app.c.

Proces ten składał się z kilku istotnych etapów:

- Przypisanie funkcji zdarzeń: Do struktury RadioEvents przypisano konkretne

funkcje, które obsługują zdarzenia związane z działaniem modułu radiowego.

„TxDone” (zakończenie transmisji), „RxDone” (zakończenie odbioru), „TxTimeout”

(przekroczenie czasu transmisji), „RxTimeout” (przekroczenie czasu odbioru), i

„RxError” (błąd przy odbiorze).

- Inicjalizacja modułu radiowego: Zainicjowano moduł radiowy za pomocą funkcji

Radio.Init(), której argumentem był wskaźnik na strukturę RadioEvents. Oznaczało to,

że moduł radiowy został zainicjowany z uwzględnieniem wcześniej zdefiniowanych

funkcji obsługi zdarzeń. W ten sposób, każde zdarzenie związane z działaniem modułu

radiowego było odpowiednio obsługiwane.

- Ustawienie kanału radiowego: Ostatnim krokiem było wywołanie funkcji

Radio.SetChannel(RF_FREQUENCY), która ustawiła częstotliwość pracy modułu

radiowego na zdefiniowaną wartość RF_FREQUENCY. Było to kluczowe dla

zapewnienia prawidłowej komunikacji na odpowiednim kanale radiowym.

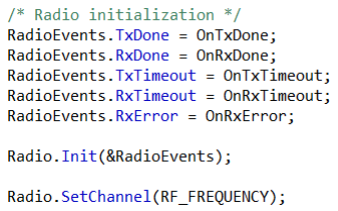
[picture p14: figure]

Rys. 16 Inicjalizacja modułu LoRa w funkcji SubghzApp_Init()

Na rys.17 przedstawiono kod źródłowy odpowiedzialny za konfigurację modułu radiowego

dla modulacji LoRa, w kontekście zarówno transmisji (Tx), jak i odbioru (Rx) danych. Za

pomocą funkcji SetMaxPayloadLength() ustawiono największy rozmiar ładunku danych, który

mógł być przetwarzany przez moduł radiowy, co było istotne dla zarządzania pamięcią.

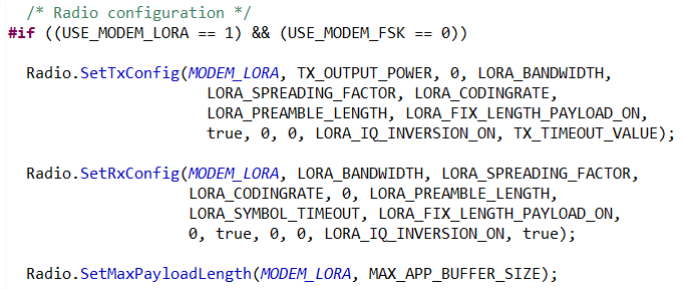
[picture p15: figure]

Rys. 17 Konfiguracja modułu LoRa w funkcji SubghzApp_Init()

Oba urządzenia, nadajnik i odbiornik, posiadają takie same parametry oraz wykonują proces

inicjalizacji w ten sam sposób dla modułu radiowego LoRa. Występuje różnica w konfiguracji

radia dla obu urządzeń, nadajnik ustawia tylko Radio.SetTxConfig(), a odbiornik

Radio.SetRxConfig().

### 5.3.2. Implementacja funkcji PingPong_Process

W rozdziale 5.3.2. przedstawiono funkcje PingPong_Process, którą zaimplementowano w

pliku subghz_phy_app.c. Odgrywa ona główną rolę w zarządzaniu komunikacją systemu

elektronicznych flag sędziowskich. Odpowiada za inicjowanie i przetwarzanie sygnałów

wymienianych między urządzeniami.

Szczegółowa analiza funkcji nadajnika

1. Pętla Nieskończona: Funkcja działa w ramach nieskończonej pętli while(1), co

oznacza, że będzie ona kontynuować swoje działanie do momentu manualnego

przerwania lub resetowania systemu.

2. Sprawdzenie Stanu Przycisku: Na początku każdego cyklu pętli, funkcja

sprawdza stan przycisku za pomocą HAL_GPIO_ReadPin. Jeśli przycisk jest

naciśnięty (stan równy 1), inicjowana jest kolejna sekwencja działań.

3. Przejście z Trybu Uśpienia do Trybu Gotowości: Gdy przycisk jest naciśnięty,

moduł radiowy jest przełączany z trybu uśpienia do trybu gotowości poprzez

wywołanie Radio.Standby().

4. Resetowanie Stanu Diody LED: Następuje włączenie diody LED (Green LED)

poprzez ustawienie jej w stan niski (GPIO_PIN_RESET).

5. Ustawienie Stanu na Transmisję (TX) i Wysyłanie Danych: Stan systemu jest

ustawiany na transmisję (TX), a następnie wysyłane są dane („PING”) za pomocą

funkcji Radio.Send. Proces ten jest powtarzany trzykrotnie z krótkim opóźnieniem

(HAL_Delay(150)) pomiędzy każdym wysłaniem.

6. Zapalenie Diody LED: Po zakończeniu wysyłania danych, dioda LED jest

ponownie ustawiana w stan wysoki (GPIO_PIN_SET).

7. Tryb Uśpienia Radia w Przypadku Braku Akcji: Jeśli przycisk nie jest

naciśnięty, radio pozostaje w trybie uśpienia (Radio.Sleep()).

Na rys. 18 przedstawiono schemat blokowy ilustrujący działanie funkcji PingPong_Process.

Diagram ten wizualizuje sekwencję działań wykonywanych przez funkcję.

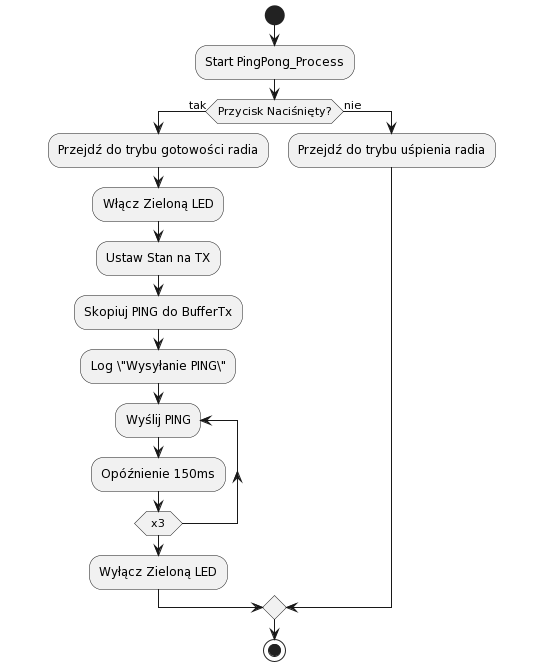
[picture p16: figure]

Rys. 18 Schemat blokowy funkcji PingPong_Process() nadajnika

Szczegółowa analiza funkcji odbiornika

Działanie tej funkcji jest sterowane przez maszynę stanów, w której reakcje są zależne od

bieżącego stanu systemu, określonego przez zmienną State. Opis zachowania funkcji w

zależności od stanu:

1. Stan RX (Odbiór): Gdy system znajduje się w stanie odbioru:
- Sprawdzane jest, czy bufor odbiorczy (RxBufferSize) zawiera jakiekolwiek

dane.

- Jeśli dane są dostępne, funkcja następnie sprawdza, czy otrzymane dane

zgadzają się ze znanym wzorcem PING za pomocą porównania łańcuchów

znaków (strncmp).

- W przypadku pozytywnego rozpoznania napisu PING, funkcja aktywuje

buzzer (przypisany do GPIOA) na jedną sekundę, co służy jako sygnalizacja

odbioru, a następnie wyłącza buzzer.

- Po aktywacji buzzera, w dzienniku systemowym rejestrowana jest

informacja o odebraniu PING.

- Następnie, moduł radiowy jest ponownie ustawiany w tryb odbioru z

zadanym czasem oczekiwania (RX_TIMEOUT_VALUE).

2. Stan RX_TIMEOUT (Przekroczenie czasu odbioru): W przypadku, gdy czas

oczekiwania na odbiór danych zostanie przekroczony, funkcja ponownie ustawia

radio w tryb odbioru, wykorzystując tę samą wartość czasu oczekiwania.

3. Stan RX_ERROR (Błąd odbioru): W sytuacji wystąpienia błędu podczas odbioru,

funkcja również resetuje moduł radiowy do trybu odbioru z zadanym czasem

oczekiwania.

4. Domyślny stan: Dla wszystkich innych stanów, które nie zostały wyraźnie

zdefiniowane, nie jest wykonywana żadna akcja.

Na rys. 19 przedstawiono schemat blokowy ilustrujący działanie funkcji PingPong_Process.

Schemat ten szczegółowo opisuje różne stany i decyzje podejmowane przez odbiornik w

zależności od bieżących warunków pracy.

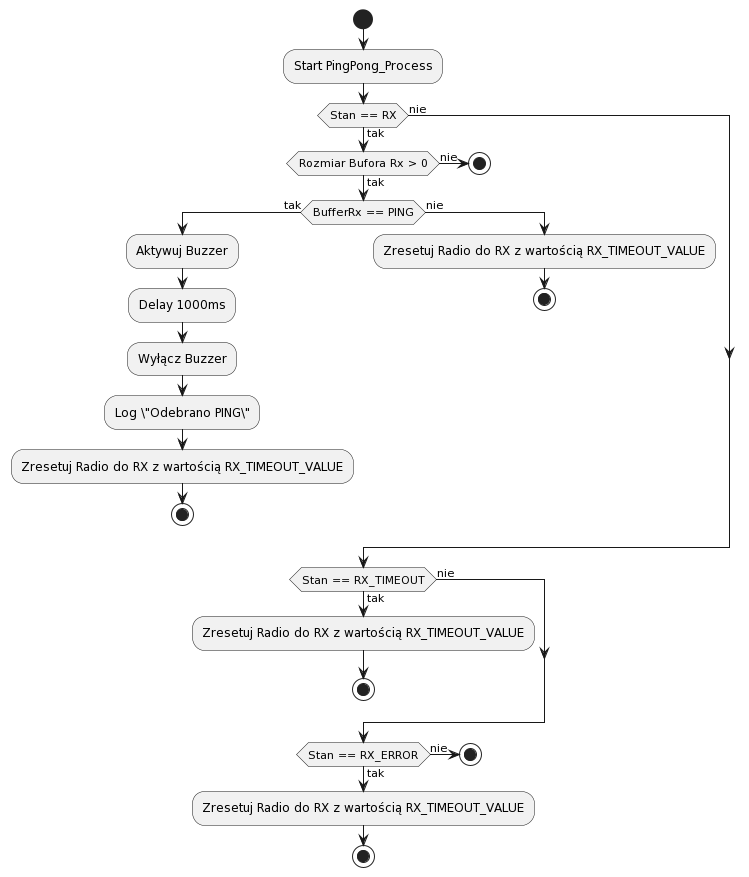
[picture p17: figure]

Rys. 19 Schemat blokowy funkcji PingPong_Process() odbiornika

## 5.4. Test oprogramowania

W procesie testowania oprogramowania szczególną uwagę poświęcono wykorzystaniu

interfejsu USART2, który odegrał kluczową rolę w diagnozowaniu i weryfikacji skuteczności

systemu komunikacyjnego. USART2, jako uniwersalny asynchroniczny odbiornik-nadajnik,

został użyty do precyzyjnego monitorowania przepływu danych oraz identyfikacji

potencjalnych problemów komunikacyjnych w czasie rzeczywistym. Jego zastosowanie

pozwoliło na dokładną analizę każdego etapu wymiany danych, od wysyłania przez nadajnik,

poprzez transmisję, aż po odbiór i przetworzenie przez odbiornik.

Na rys. 20 widać, że nadajnik trzykrotnie wszedł w tryb transmisji po aktywacji przez

użytkownika (naciśnięcie przycisku), co jest zasygnalizowane przez logi "OnTxDone".

Rys. 20 Terminal nadajnika potwierdzający trzykrotne wysłanie sygnału

Na rys. 21 można zaobserwować, że urządzenie poprawnie odbiera transmisje "PING" od

nadajnika, co potwierdza log "Odebrano PING". Dodatkowo, odbiornik rejestruje informacje o

sile sygnału (RSSI) i stosunku sygnału do szumu (SNR), co jest ważne dla oceny jakości

łączności i poziomu zakłóceń. Odbiornik również doświadcza stanów "OnRxTimeout", co

oznacza, że w danym momencie nie odebrano żadnego sygnału.

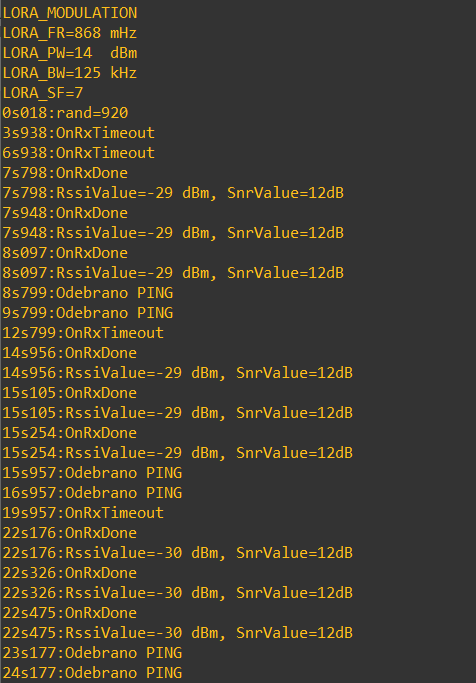
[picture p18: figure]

Rys. 21 Terminal odbiornika potwierdzający trzykrotne odebranie sygnału

Na podstawie tych wyników można stwierdzić, że implementacja oprogramowania spełnia

założone wymagania funkcjonalne. Komunikacja między poszczególnymi modułami przebiega

zgodnie z oczekiwaniami, co jest kluczowe dla stabilności i efektywności całego systemu.

## 6. Testy i weryfikacja systemu

## 6.1. Testy poboru prądu

### 6.1.1. Wprowadzenie

W podrozdziale 6.1. skupiono się na analizie poboru prądu przez nadajnik i odbiornik w

systemie flag sędziowskich. Do pomiaru pradu wykorzystano przyrząd Keysight N6705C DC

Power Analyzer wraz z oprogramowaniem, który umożliwia dokładne śledzenie i rejestrowanie

wzorców poboru prądu przez urządzenia.

Zarówno nadajnik, jak i odbiornik zasilany jest dwoma bateriami AAA, z których każda ma

pojemność 1350 mAh. Ta informacja jest istotna dla oszacowania żywotności baterii i ogólnej

wydajności urządzeń podczas meczu.

Celem tej analizy jest nie tylko zrozumienie bieżącej wydajności tych urządzeń, ale również

identyfikacja możliwych obszarów dla ich dalszego rozwoju i usprawnienia, aby zapewnić

maksymalną efektywność i niezawodność w trakcie rozgrywek piłkarskich.

### 6.1.2. Analiza poboru prądu nadajnika

Rys. 22 przedstawia wykres zależności natężenia prądu od czasu dla nadajnika systemu

radiowego. Na jego podstawie odczytano, że podczas stanu uśpienia urządzenia natężenie prądu

utrzymuje się na poziomie około 6 mA. Natomiast, gdy urządzenie jest aktywne, natężenie

prądu wzrasta do wartości w okolicach 13 mA.

Na wykresie można zauważyć regularne, niewielkie wzrosty natężenie prądu do wartości

około 8 mA, które pojawiają się z częstotliwością co około jedną sekundę. Powodem tego jest

jednosekundowe opóźnienie, które zaimplementowane było w starszej wersji oprogramowania,

po przejściu radia w stan uśpienia.

Momenty, w których natężenie prądu przez dłuższy czas wynosi około 7-8 mA, to czas,

kiedy dioda LED jest włączona.

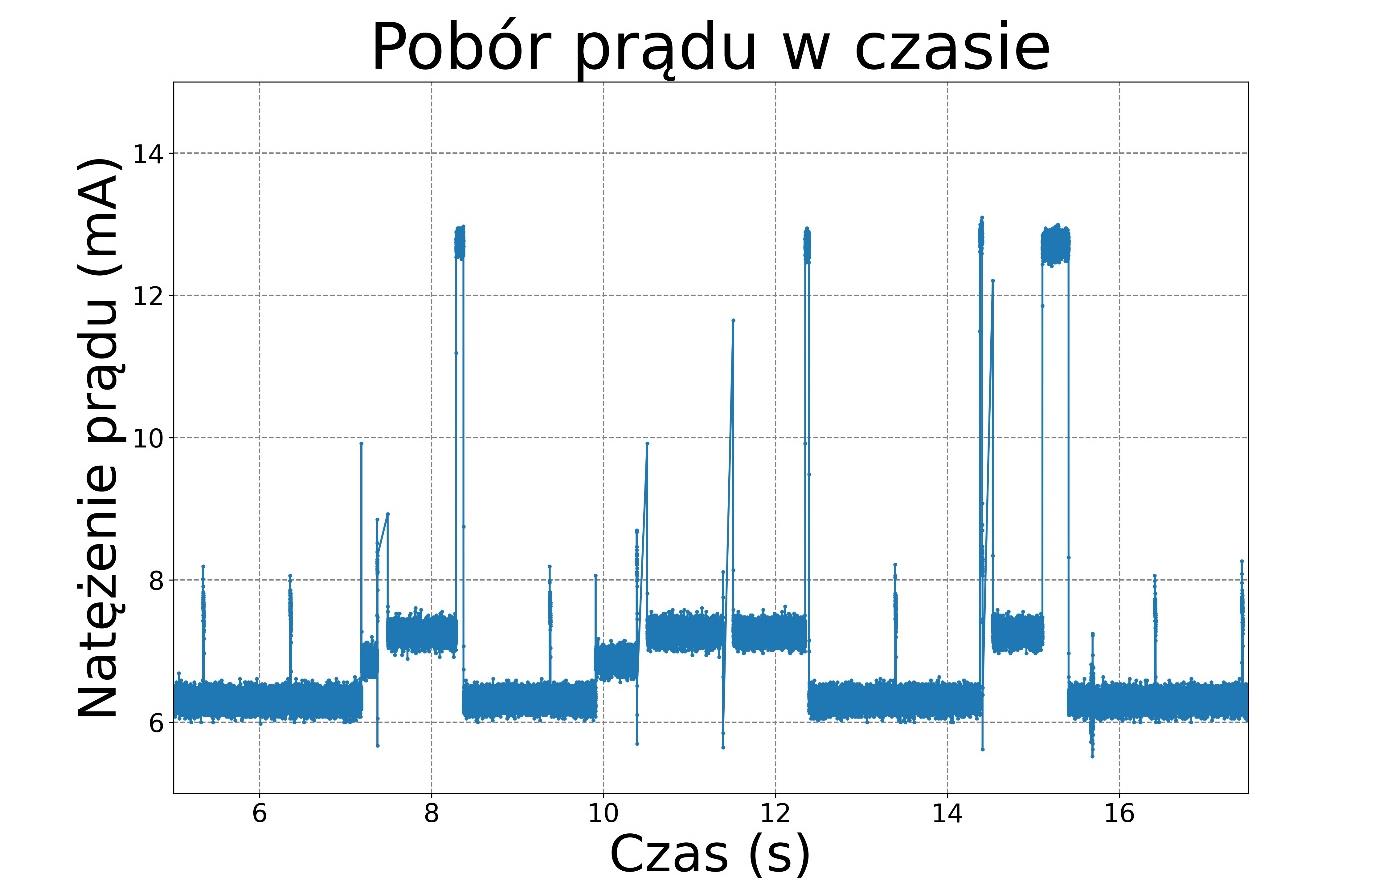
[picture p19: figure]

Rys. 22 Wykres poboru prądu w czasie nadajnika

Analiza poboru prądu nadajnika
1. Założenia początkowe:
- Pojemność baterii: 2700mAh
- Łączny czas meczu, w tym przerwy i czas dodatkowy: tmecz = 7200 s.
- Liczba aktywacji nadajnika: Naktywacje = 50.
- Czas trwania jednej aktywacji: taktywacja = 1 s.
- Pobór prądu nadajnika w stanie aktywnym: Iaktywny = 13 mA.
- Pobór prądu nadajnika w stanie uśpienia: Iuśpienie = 6 mA.
- Liczba meczy w miesiącu: Nmecze = 8.
- Samorozładowanie baterii w ciągu miesiąca: Sroz = 2%.
2. Obliczenie zużycia prądu podczas meczu:
- Ładunek | zużyty | podczas | aktywacji: | Qaktywacja = Naktywacje ∗

taktywacja ∗ Iaktywny.

- Ładunek zużyty w stanie uśpienia: Quśpienie = (tmecz − Naktywacje ∗

taktywacja) ∗ Iuśpienie.

- Całkowity ładunek zużyty podczas meczu: Qmecz = Qaktywacja +

Quśpienie.

### 3. Obliczenie miesięcznego zużycia ładunku:

- Miesięczne zużycie ładunku: Qmiesięczne = Qmecz ∗ Nmecze.

### 4. Obliczenie samorozładowania baterii:

- Miesięczna strata na samorozładowanie: Qroz = Sroz ∗ 2700 mAℎ.

### 5. Łączne miesięczne zużycie energii:

- Łączne zużycie energii z uwzględnieniem samorozładowania: Qłączne =

Qmiesięczne + Qroz.

### 6. Obliczenie żywotności baterii:

- Żywotność baterii: Tbateria =

2700 mAℎ

Qłączne

### 7. Obliczenie liczby meczy na jednym zestawie baterii:

- Łączna liczba meczy: Nłącznie = Tbateria ∗ Nmecze.
8. Wnioski i implikacje:
- Na podstawie powyższych obliczeń, średnie zużycie prądu przez nadajnik

podczas jednego meczu wynosi około 12.1 mAh.

- Miesięczne zużycie energii to 96.8 mAh, a po uwzględnieniu samorozładowania

wynosi to 150.8 mAh.

- Łączny czas życia baterii przy takim zużyciu wynosi około 18 miesięcy.
- Oznacza to, że na jednym zestawie baterii można przeprowadzić około 143

meczy piłkarskich.

Podsumowanie

Analiza wskazuje na wysoką efektywność energetyczną nadajnika, co zapewnia długą

żywotność baterii i niezawodność urządzenia w trakcie rozgrywek, nawet w przypadku

dłuższych meczów z przerwami i czasem dodatkowym. Długotrwałe działanie nadajnika bez

konieczności częstej wymiany baterii jest kluczowe dla efektywności i praktyczności urządzeń

stosowanych w sporcie.

### 6.1.3. Analiza poboru prądu odbiornika

Rys. 23 przedstawia wykres zależności natężenia prądu od czasu dla odbiornika systemu

radiowego. Na jego podstawie odczytano, że podczas stanu uśpienia urządzenia natężenie prądu

utrzymuje się na poziomie około 6 mA. Natomiast, gdy urządzenie jest aktywne, średnie

natężenie prądu wynosi około 30 mA. Okresy, w którym buzzer jest aktywny, trwają około

jedną sekundę.

Momenty, w których natężenie prądu przez dłuższy czas wynosi około 12-13 mA, to czas,

kiedy dioda LED jest włączona.

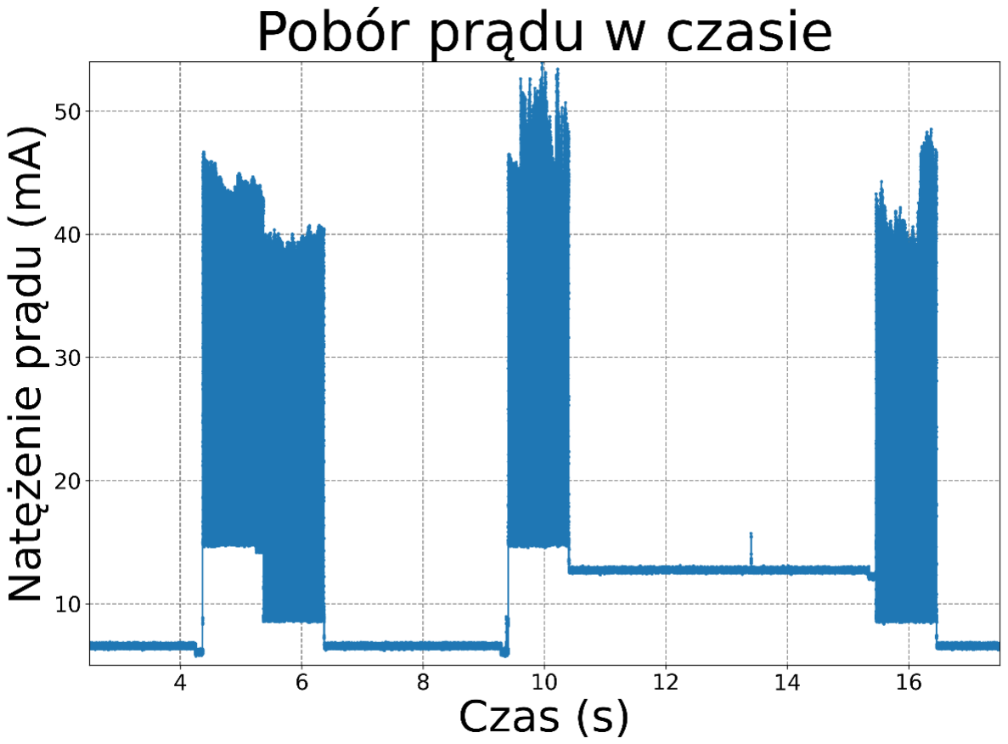
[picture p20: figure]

Rys. 23 Wykres poboru prądu w czasie odbiornika

Analizę poboru prądu odbiornika

### 1. Zużycie prądu podczas meczu:

- Pobór prądu odbiornika w stanie aktywnym: Iaktywny = 30 mA.
- Pobór prądu odbiornika w stanie odbioru: Iodbioru = 6 mA.
- Ładunek | zużyty | podczas | aktywacji: | Qaktywacja_odb = Naktywacje ∗

taktywacja ∗ Iaktywny.

- Ładunek zużyty w stanie odbioru: Qodbioru_odb = (tmecz − Naktywacje ∗

taktywacja) ∗ Iodbioru.

- Całkowity ładunek zużyty podczas meczu: Qmecz_odb = Qaktywacja_odb +

Qodbioru_odb.

### 2. Miesięczne zużycie prądu:

- Miesięczne zużycie ładunku: Qmiesięczne_ocb = Qmecz_odb ∗ Nmecze.

### 3. Samorozładowanie baterii:

- Miesięczna strata na samorozładowanie: Qroz_odb = Sroz ∗ 2700 mAℎ.

### 4. Łączne miesięczne zużycie energii:

- Łączne zużycie energii z uwzględnieniem samorozładowania: Qłączne_odb =

Qmiesięczne_odb + Qroz_odb.

### 5. Żywotność baterii:

- Żywotność baterii: Tbateria_odb =

2700 mAℎ

Qłączne_odb

### 6. Liczba meczów na jednym zestawie baterii:

- Łączna liczba meczy: Nłącznie_odb = Tbateria_odb ∗ Nmecze.

### 7. Wnioski i implikacje:

- Na podstawie powyższych obliczeń, średnie zużycie prądu przez odbiornik

podczas jednego meczu wynosi około 12.3 mAh.

- Miesięczne zużycie energii to 98.7 mAh, a po uwzględnieniu samorozładowania

wynosi to 152.7 mAh.

- Łączny czas życia baterii przy takim zużyciu wynosi około 17.5 miesiąca.
- Oznacza to, że na jednym zestawie baterii można przeprowadzić około 141

meczy piłkarskich.

Podsumowanie

Analiza wykazała, że odbiornik jest wysoce efektywny energetycznie, co zapewnia jego

długą żywotność baterii i niezawodność działania w trakcie rozgrywek. Nawet przy

zwiększonym czasie trwania meczu, długość pracy odbiornika na jednym zestawie baterii jest

imponująca, co podkreśla jego praktyczność w kontekście sportowym.

### 6.1.4. Wnioski

Bazując na zrealizowanych pomiarach wprowadzono następujące modyfikacje w

oprogramowaniu:

### 1. Modyfikacja odbiornika:

- Po przeprowadzeniu badań, zdecydowano się na wyłączenie diody w odbiorniku.

Obserwacje wykazały, że dioda ta miała wpływ na zwiększenie poboru prądu.

Usunięcie tej funkcji przyczyniło się do zmniejszenia zużycia energii, co jest kluczowe

w kontekście efektywności energetycznej urządzenia.

### 2. Zmiany w nadajniku:

- W nadajniku wprowadzono zmiany w sekwencji wysyłania sygnału. Obecnie sygnał

jest wysyłany w formie potrójnej, z opóźnieniami 150 [ms] między poszczególnymi

sygnałami. Ta modyfikacja pozwala na bardziej efektywną komunikację i zwiększa

niezawodność przesyłu danych.

## 6.2. Testy zasięgu komunikacji

### 6.2.1. Wprowadzenie

Celem przeprowadzonych testów zasięgu było zmierzenie efektywności komunikacji

bezprzewodowej w różnych odległościach, aby sprawdzić jej niezawodność w ramach

maksymalnego zakładanego zasięgu operacyjnego. Ustalono, że minimalny wymagany zasięg

wynosi 150 metrów, co odpowiada największej możliwej odległości na boisku piłkarskim,

mierzonej w linii prostej pomiędzy dwoma najdalszymi punktami – czyli wzdłuż przekątnej

boiska. Takie założenie stanowi podstawę do zapewnienia, że system będzie funkcjonował bez

zakłóceń w kontekście przewidzianego użytkowania, co jest krytyczne dla aplikacji, gdzie

stabilność łączności ma bezpośredni wpływ na ogólną wydajność i jakość podejmowanych

decyzji. Testy zasięgu są niezbędne do potwierdzenia, że system spełnia te fundamentalne

wymogi, co gwarantuje użytkownikom pewność, iż komunikacja zostanie utrzymana nawet na

skrajach zdefiniowanego obszaru działania.

### 6.2.2. Sprzęt i Metodyka Testów

W procesie testowania wykorzystano nadajnik i odbiornik bezprzewodowy, które zostały

szczegółowo opisane w poprzednich rozdziałach niniejszej pracy. Aby zmierzyć zasięg

komunikacji, posłużono się aplikacją GPSFieldAreaMeasure, która umożliwia dokładne

określenie dystansu pomiędzy dwoma punktami.

Test 1: Boisko Piłkarskie

Pierwszy test zasięgu został wykonany na boisku piłkarskim. W tym ustawieniu, jedna osoba

z odbiornikiem i komputerem stała w jednym końcu boiska (punkt A), a druga osoba z

nadajnikiem udała się do przeciwnego końca (punkt B). Miejsce to zapewniało otwartą

przestrzeń bez większych przeszkód dla sygnału.

Testy 2 i 3: Teren Otwarty

Kolejne dwa testy przeprowadzono w innych lokalizacjach na terenie otwartym. Warunki

pogodowe podczas tych testów były idealne – bezchmurne niebo i brak opadów deszczu. W

otoczeniu znajdowały się jednak pojedyncze drzewa i pojazdy, które mogły wpłynąć na

propagację sygnału.

Wyniki testów udokumentowano za pomocą zrzutów ekranu z aplikacji pomiarowej oraz

terminali nadajnika i odbiornika, aby zapewnić pełną przejrzystość i możliwość weryfikacji

otrzymanych danych.

### 6.2.3. Prezentacja wyników

Test 1: Boisko piłkarskie

Na rys. 24 można zauważyć, że odległość pomiarowa wyniosła około 64 metry. Warunki

atmosferyczne podczas testów były bardzo dobre – bezchmurne niebo oraz brak opadów.

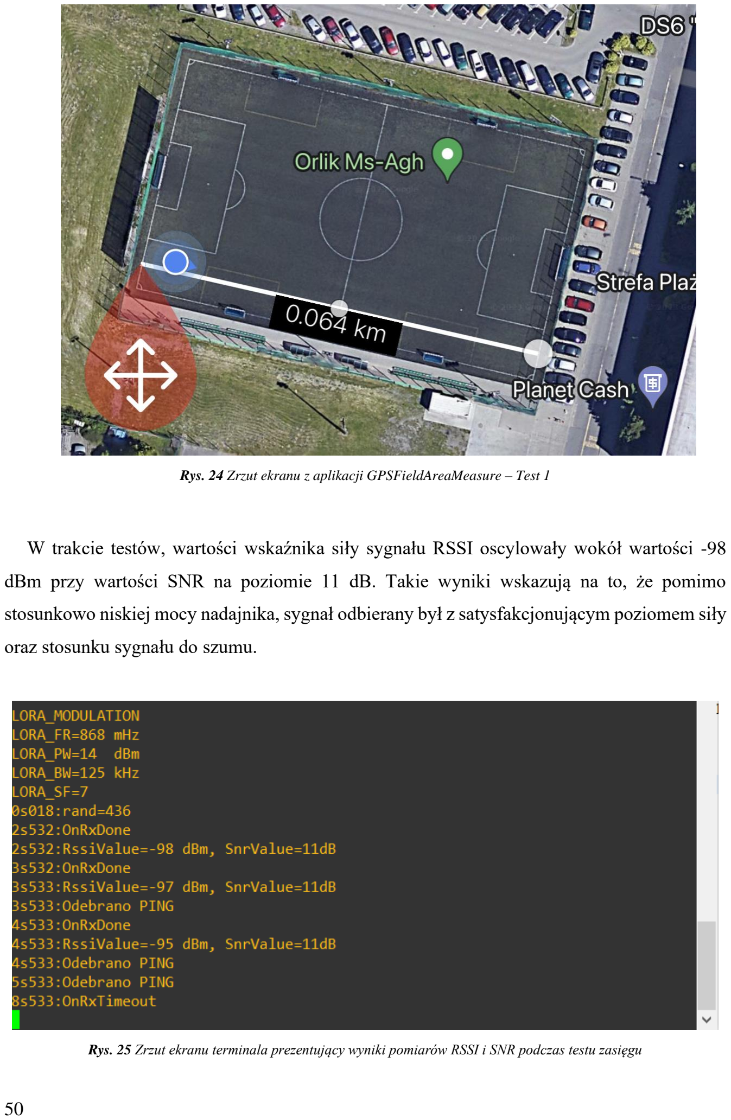
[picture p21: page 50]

Rys. 24 Zrzut ekranu z aplikacji GPSFieldAreaMeasure – Test 1

W trakcie testów, wartości wskaźnika siły sygnału RSSI oscylowały wokół wartości -98

dBm przy wartości SNR na poziomie 11 dB. Takie wyniki wskazują na to, że pomimo

stosunkowo niskiej mocy nadajnika, sygnał odbierany był z satysfakcjonującym poziomem siły

oraz stosunku sygnału do szumu.

Rys. 25 Zrzut ekranu terminala prezentujący wyniki pomiarów RSSI i SNR podczas testu zasięgu

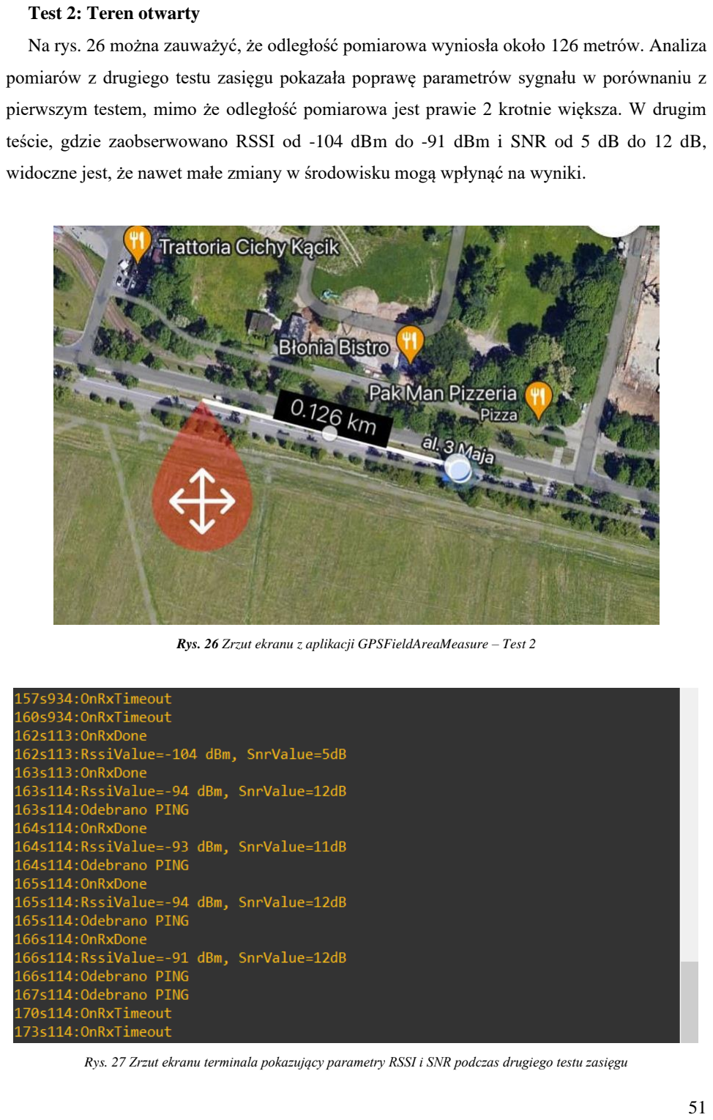
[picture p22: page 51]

Test 2: Teren otwarty

Na rys. 26 można zauważyć, że odległość pomiarowa wyniosła około 126 metrów. Analiza

pomiarów z drugiego testu zasięgu pokazała poprawę parametrów sygnału w porównaniu z

pierwszym testem, mimo że odległość pomiarowa jest prawie 2 krotnie większa. W drugim

teście, gdzie zaobserwowano RSSI od -104 dBm do -91 dBm i SNR od 5 dB do 12 dB,

widoczne jest, że nawet małe zmiany w środowisku mogą wpłynąć na wyniki.

Rys. 26 Zrzut ekranu z aplikacji GPSFieldAreaMeasure – Test 2

Rys. 27 Zrzut ekranu terminala pokazujący parametry RSSI i SNR podczas drugiego testu zasięgu

Test 3: Teren otwarty

Trzeci test zasięgu przeprowadzony na dystansie 529 metrów, wykazał, że sygnał LoRa jest

zdolny do pokonania większych odległości niż oczekiwano. Odczyty RSSI utrzymywały się na

poziomie -111 do -113 dBm, co, mimo że są to wartości niższe (wskazujące na słabszy sygnał),

nadal znajdują się w zakresie umożliwiającym komunikację. Wartości SNR wahały się od -2

do 0 dB, co sugeruje, że sygnał był bliski granicy detekcji i że stosunek sygnału do szumu był

na bardzo niskim poziomie, co jest typowe dla sygnałów odbieranych na krawędziach zasięgu.

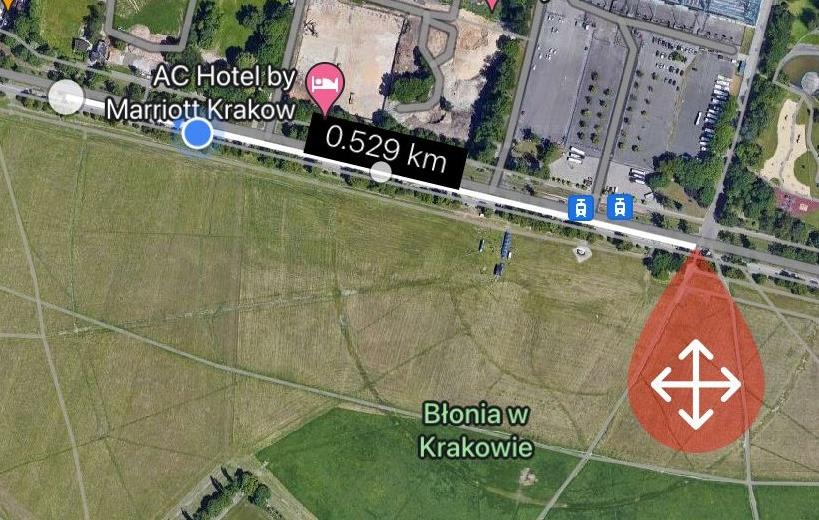
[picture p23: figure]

Rys. 28 Zrzut ekranu z aplikacji GPSFieldAreaMeasure – Test 3

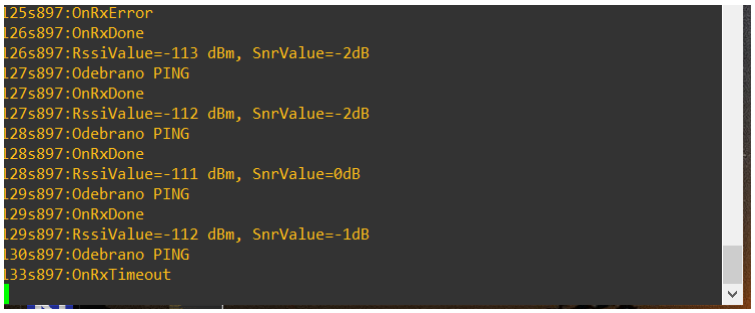
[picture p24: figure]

Rys. 29 Zrzut ekranu terminala pokazujący parametry RSSI i SNR podczas trzeciego testu zasięgu

### 6.2.4. Wnioski

Podsumowując wykonane pomiary, można stwierdzić, że system komunikacyjny z

modulacją LoRa spełnia postawione przed nim oczekiwania w kontekście zasięgu i stabilności

sygnału. Analiza wyników wskazuje na to, że technologia ta jest zdolna do efektywnego

działania na różnych odległościach, w środowisku miejskim oraz otwartym. co otwiera drogę

do jej zastosowania w kontekście zarządzania zdarzeniami masowymi, takimi jak mecze

piłkarskie.

Wartości RSSI i SNR, mimo iż w niektórych przypadkach były bliskie granic detekcji,

potwierdziły zdolność systemu do utrzymania komunikacji w miejskich warunkach, nawet

przy obecności typowych przeszkód. Wykazano, że LoRa może być skutecznie wykorzystana

w miejscach, gdzie tradycyjne systemy komunikacyjne mogłyby zawieść, szczególnie w

sytuacjach dużego obciążenia sieci.

Dalsze testy i badania powinny zostać przeprowadzone w celu optymalizacji parametrów

sieci i infrastruktury, aby dostosować system do specyficznych wymagań i warunków, w jakich

ma być eksploatowany. Jednakże, już na tym etapie można wnioskować, że technologia LoRa

posiada istotny potencjał dla aplikacji wymagających długiego zasięgu i niskiego zużycia

energii, takich jak elektroniczne chorągiewki sędziowskie, które wymagają niezawodnej

komunikacji bezprzewodowej na rozległych obszarach, takich jak stadiony piłkarskie.

## 7. Podsumowanie

W projekcie dyplomowym zaprojektowano i wykonano prototyp elektronicznych flag

sędziowskich oraz odbiornika, które komunikują się bezprzewodowo za pomocą technologii

LoRa. Celem była realizacja niedrogiego i skutecznego systemu komunikacji dla sędziów

sportowych, zwłaszcza na niższych szczeblach rozgrywek.

W projekcie skupiono się na zastosowaniu technologii LoRa, która umożliwiła efektywną

komunikację na duże odległości przy minimalnym zużyciu energii. Zaprojektowano

specjalistyczne płytki drukowane PCB dla nadajnika i odbiornika, zwracając uwagę na ich

kompatybilność z rękojeściami flag oraz obudowami odbiorników. Ważnym aspektem była

ergonomia i funkcjonalność, w tym umiejscowienie przycisku w rękojeści flagi oraz integracja

elementu sygnalizacyjnego w odbiorniku.

Opracowanie oprogramowania odbyło się w środowisku STM32CubeIDE, co zapewniło

efektywną pracę z modułami RAK3172. Zaimplementowano program sterujący modułami, w

tym funkcję PingPong_Process, odpowiedzialną za zarządzanie komunikacją między

nadajnikiem a odbiornikiem.

Testy zasięgu i poboru prądu wykazały wysoką efektywność systemu. Osiągnięty zasięg

komunikacji przekroczył oczekiwania, podczas gdy niskie zużycie energii potwierdziło

skuteczność zastosowanej technologii. Wyniki te wskazują na funkcjonalność oraz

efektywność kosztową systemu, czyniąc go dostępnym dla szerszej grupy sędziów.

Możliwe ulepszenia obejmują dalszą optymalizację konstrukcji PCB i oprogramowania,

zwiększenie interaktywności systemu przez dodanie wizualnych wskaźników oraz integrację z

innymi systemami wykorzystywanymi w trakcie meczów. Projekt otwiera nowe możliwości w

dziedzinie technologii sportowych, podkreślając znaczenie innowacyjnych rozwiązań

komunikacyjnych w poprawie jakości i sprawiedliwości rozgrywek.

## 8. Bibliografia

[1] Strona internetowa firmy SignalBip (28.12.2023):

https://signalbip.com/en/130-rechargeable-electronic-beeper-flags.html

[2] Strona internetowa refereestore z ofertą flag ErvoCom (28.12.2023):

https://www.refereestore.com/new-model-ervocom-electronic-flags-set-of-2/

[3] Laurens Slats: A Brief History of LoRa®: Three Inventors Share Their Personal Story at The Things Conference, 8 Stycznia 2020 :

https://blog.semtech.com/a-brief-history-of-lora-three-inventors-share-their-personal-story-at-the-things-conference (https://blog.semtech.com/a-brief-history-of-lora-three-inventors-share-their-personal-story-at-the-things-conference)

[4] TEKTELIC Communications Inc.: LoRaWAN - Most Common Applications and Use Cases, 16 Stycznia 2023:

https://www.iotforall.com/lorawan-most-common-applications-and-use-cases

[5] Semtech Corporation: AN1200.22 LoRa™ Modulation Basics, Maj 2015
[6] Krzysztof Chojnowski: LoRa na STM32 i SX1276 – jaki jest realny zasięg transmisji?, 13 Grudnia 2017:

https://mikrokontroler.pl/2017/12/13/lora-stm32-sx1276-realny-zasieg-transmisji/

[7] Eric B.: LoRa, 2018:

https://lora.readthedocs.io/en/latest/

[8] Strona internetowa firmy botland (28.12.2023):

https://botland.com.pl/programatory/22109-stlink-v3minie-debugger-i-programator-do-mikrokontrolerow-stm32-stmicroelectronics.html (https://botland.com.pl/programatory/22109-stlink-v3minie-debugger-i-programator-do-mikrokontrolerow-stm32-stmicroelectronics.html)

[9] RAK3172 WisDuo LPWAN Module Datasheet:

https://docs.rakwireless.com/Product-Categories/WisDuo/RAK3172-Module/Datasheet/

[10] Strona internetowa firmy taoglas, dokumentacja anteny (28.12.2023):

https://www.taoglas.com/product/ti-08-c-0111-868mhz-band-terminal-antenna/

[11] Strona internetowa firmy botland, oferta obudowy (28.12.2023):

https://botland.com.pl/obudowy/14199-obudowa-plastikowa-maszczyk-km-79a-abs-101x81x31mm-czarny-5904422377533.html (https://botland.com.pl/obudowy/14199-obudowa-plastikowa-maszczyk-km-79a-abs-101x81x31mm-czarny-5904422377533.html)

[12] Strona internetowa firmy mouser, dokumentacja buzzera (28.12.2023):

https://eu.mouser.com/datasheet/2/1005/2021011439f2a-2325696.pdf

[13] Strona internetowa firmy onsemi, dokumentacja tranzystora (28.12.2023):

https://www.onsemi.com/pdf/datasheet/2n3903-d.pdf

[14] Strona internetowa firmy ST, STM32CubeWL (28.12.2023):

https://www.st.com/en/embedded-software/stm32cubewl.html

[15] Krzysztof Paprocki, Biblioteki CMSIS dla STM32 ver. 3.1.0, 4 Sierpnia 2010:

https://mikrokontroler.pl/2010/08/04/biblioteki-cmsis-dla-stm32-ver-3-1-0/

[16] Andrew Larkin/Arcadius Systems: ProjectSetup for RAK3172 module in STM32CubeIDE v1.13.1, 1 Września 2023

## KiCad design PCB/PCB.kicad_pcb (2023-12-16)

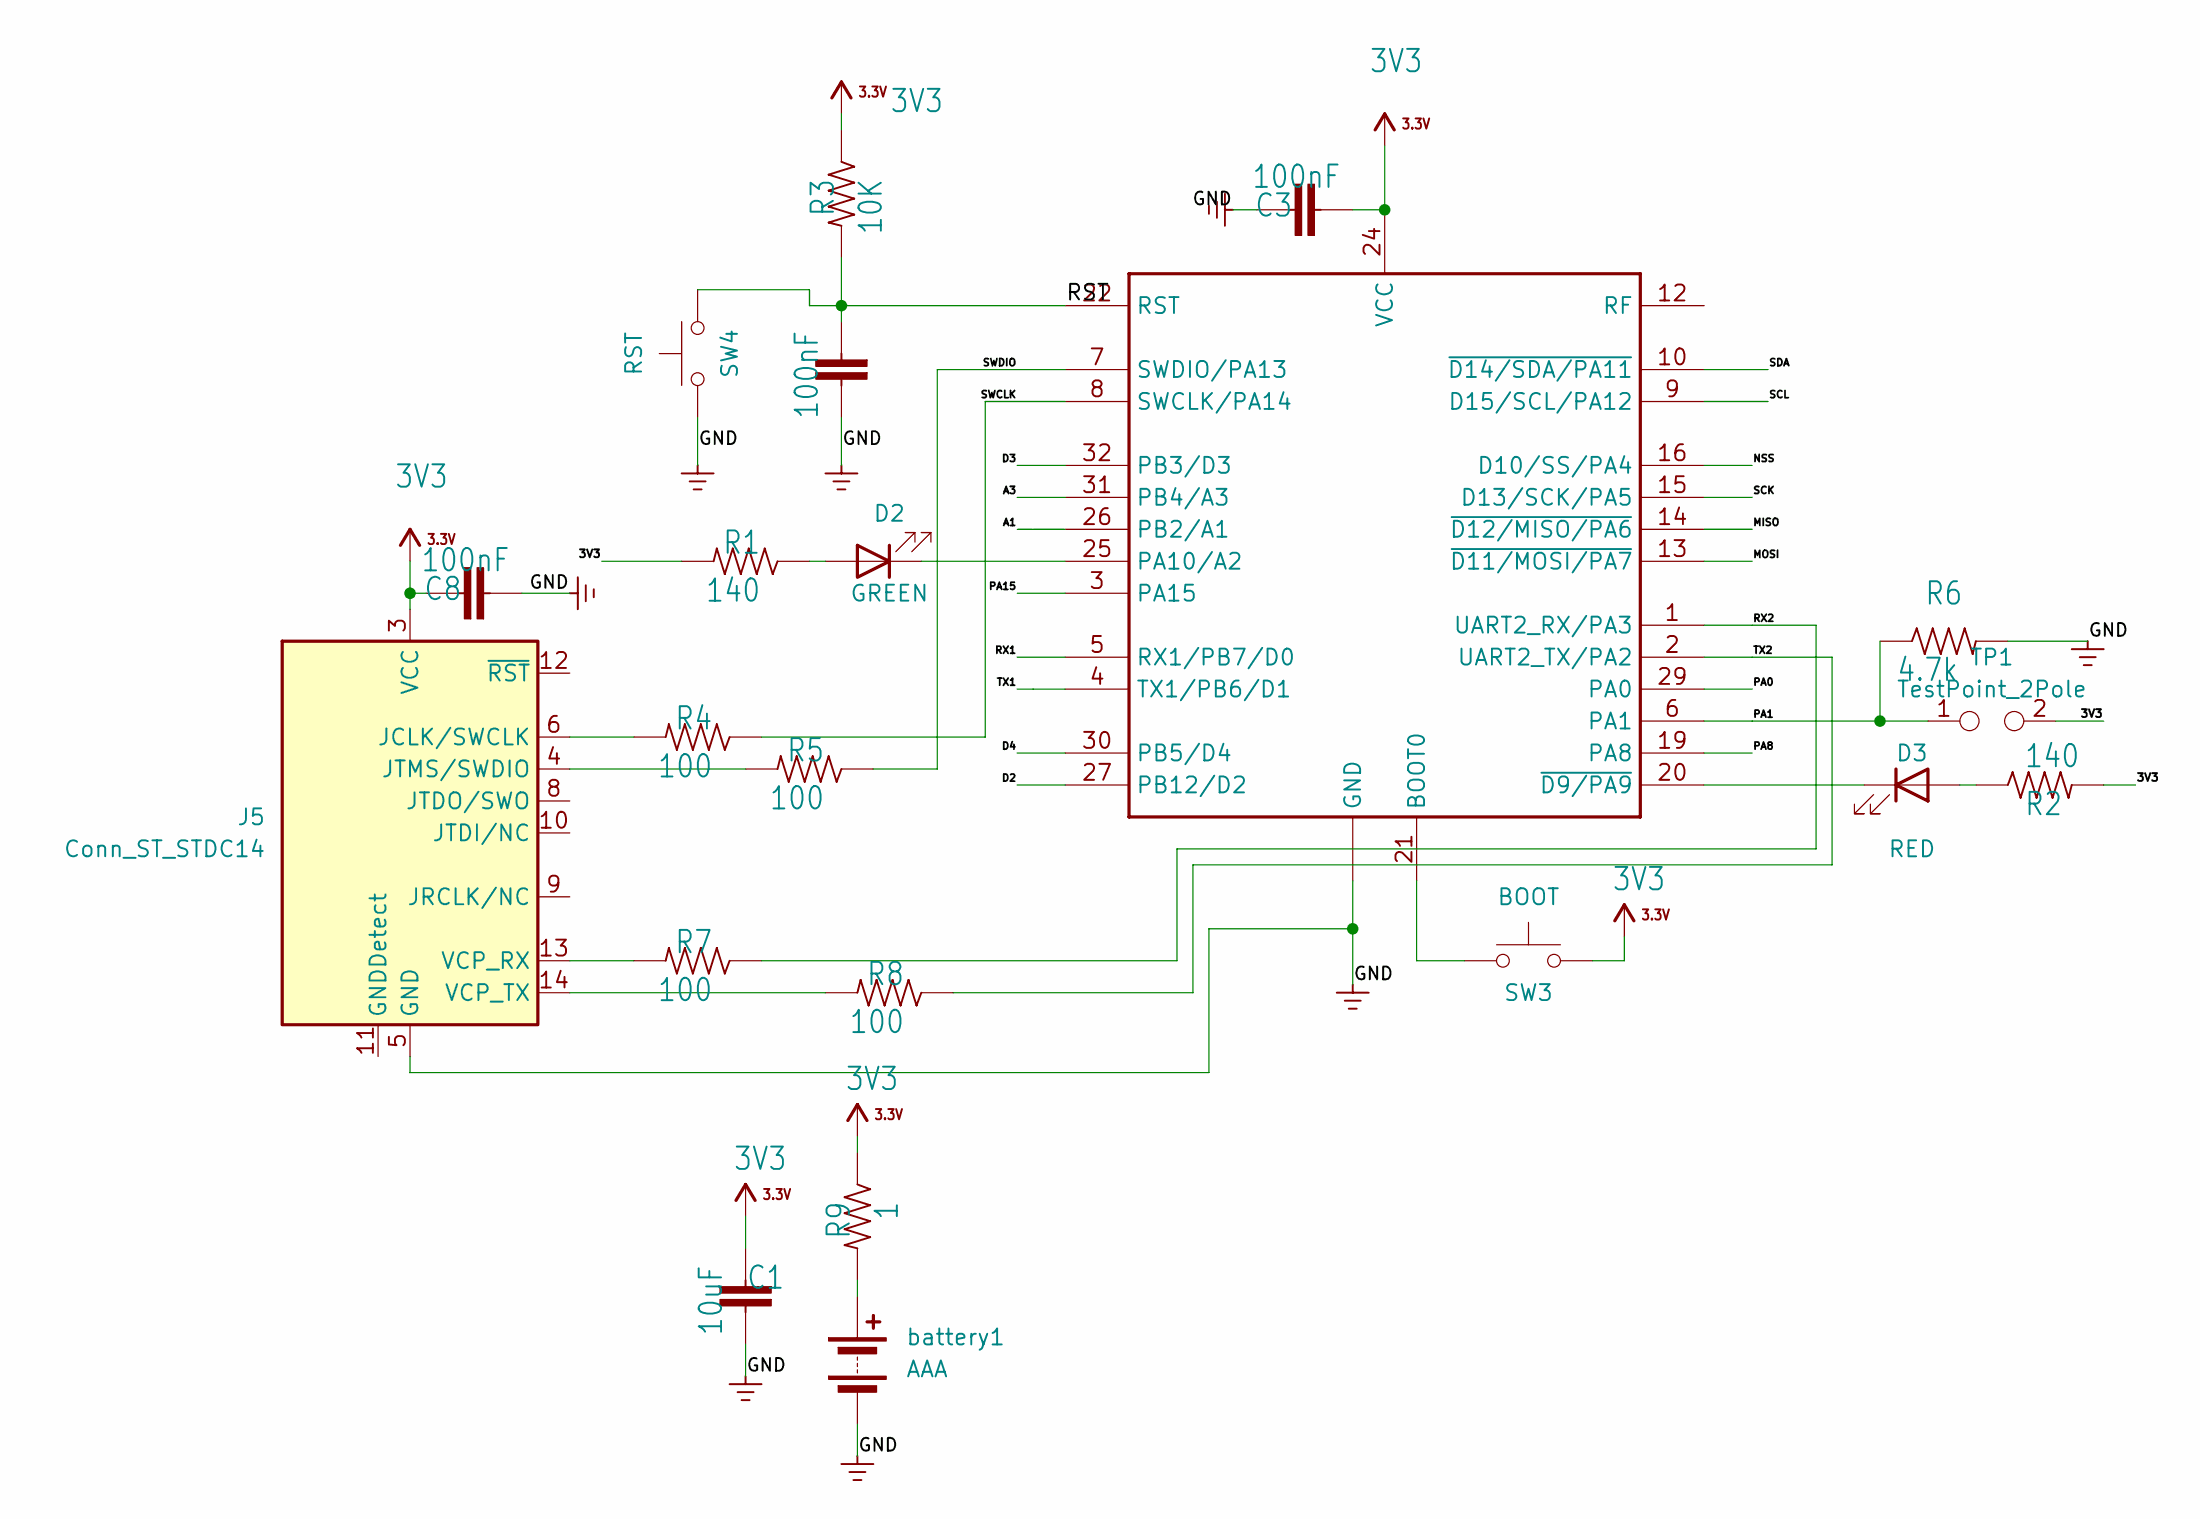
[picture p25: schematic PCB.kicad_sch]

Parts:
C1: 10uF; C_0603_1608Metric_Pad1.08x0.95mm_HandSolder
C2, C3, C8: 100nF; C_0603_1608Metric_Pad1.08x0.95mm_HandSolder
D2: GREEN; D_0603_1608Metric_Pad1.05x0.95mm_HandSolder
D3: RED; D_0603_1608Metric_Pad1.05x0.95mm_HandSolder
J5: Conn_ST_STDC14; PinHeader_2x07_P1.27mm_Vertical_SMD
R1, R2: 140; R_0603_1608Metric_Pad0.98x0.95mm_HandSolder
R3: 10K; R_0603_1608Metric_Pad0.98x0.95mm_HandSolder
R4, R5, R7, R8: 100; R_0603_1608Metric_Pad0.98x0.95mm_HandSolder
R6: 4.7k; R_0603_1608Metric_Pad0.98x0.95mm_HandSolder
R9: 1; R_0603_1608Metric_Pad0.98x0.95mm_HandSolder
SW3: BOOT; SW_SPST_B3U-1000P
SW4: RST; SW_SPST_B3U-1000P
TP1: TestPoint_2Pole; TestPoint_2Pads_Pitch2.54mm_Drill0.8mm
U$3: RAK3172HF; 3drak
battery1: AAA; PinHeader_1x02_P2.54mm_Vertical

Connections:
3V3: C1.2, C3.2, C8.1, J5.3 (VCC), R1.2, R2.2, R3.1, R9.1, SW3.2, TP1.2, U$3.24 (VCC)
/A1: U$3.26 (PB2/A1)
/A3: U$3.31 (PB4/A3)
/D2: U$3.27 (PB12/D2)
/D3: U$3.32 (PB3/D3)
/D4: U$3.30 (PB5/D4)
/MISO: U$3.14 (~D12/MISO/PA6)
/MOSI: U$3.13 (~D11/MOSI/PA7)
/NSS: U$3.16 (D10/SS/PA4)
/PA0: U$3.29 (PA0)
/PA1: R6.1, TP1.1, U$3.6 (PA1)
/PA8: U$3.19 (PA8)
/PA15: U$3.3 (PA15)
/RST: C2.2, R3.2, SW4.2, U$3.22 (RST)
/RX1: U$3.5 (RX1/PB7/D0~)
/RX2: R7.1, U$3.1 (UART2_RX/PA3)
/SCK: U$3.15 (D13/SCK/PA5)
/SCL: U$3.9 (D15/SCL/PA12)
/SDA: U$3.10 (~D14/SDA/PA11)
/SWCLK: R4.1, U$3.8 (SWCLK/PA14)
/SWDIO: R5.1, U$3.7 (SWDIO/PA13)
/TX1: U$3.4 (TX1/PB6/D1~)
/TX2: R8.1, U$3.2 (UART2_TX/PA2)
GND: C1.1, C2.1, C3.1, C8.2, J5.5 (GND), J5.7 (GND), R6.2, SW4.1, U$3.11 (GND), U$3.17 (GND), U$3.18 (GND), U$3.23 (GND), U$3.28 (GND), battery1.2 (-)
unnamed: D2.2 (A), R1.1
unnamed: D2.1 (K), U$3.25 (PA10/A2~)
unnamed: D3.2 (A), R2.1
unnamed: D3.1 (K), U$3.20 (~D9/PA9)
unnamed: J5.6 (JCLK/SWCLK), R4.2
unnamed: J5.4 (JTMS/SWDIO), R5.2
unnamed: J5.13 (VCP_RX), R7.2
unnamed: J5.14 (VCP_TX), R8.2
unnamed: SW3.1, U$3.21 (BOOT0)
unnamed: R9.2, battery1.1 (+)

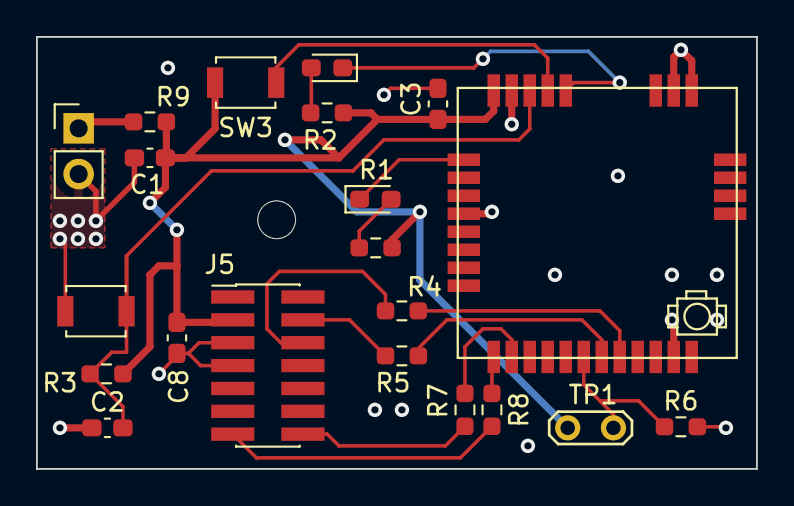
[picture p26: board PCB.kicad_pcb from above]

Board: 2 copper layers, 40.0 x 24.0 mm, 21 parts (0 on the bottom side), 18 nets.

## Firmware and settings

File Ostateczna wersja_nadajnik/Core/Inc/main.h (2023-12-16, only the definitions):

#define RTC_PREDIV_A ((1<<(15-RTC_N_PREDIV_S))-1)
#define RTC_N_PREDIV_S 10
#define RTC_PREDIV_S ((1<<RTC_N_PREDIV_S)-1)
#define RF_SW_CTRL1_Pin GPIO_PIN_8
#define RF_SW_CTRL1_GPIO_Port GPIOB
#define Button_Pin GPIO_PIN_1
#define Button_GPIO_Port GPIOA
#define Button_EXTI_IRQn EXTI1_IRQn
#define TX2_Pin GPIO_PIN_2
#define TX2_GPIO_Port GPIOA
#define RX2_Pin GPIO_PIN_3
#define RX2_GPIO_Port GPIOA
#define FREQ_HIGH_Pin GPIO_PIN_12
#define FREQ_HIGH_GPIO_Port GPIOB
#define Green_LED_Pin GPIO_PIN_10
#define Green_LED_GPIO_Port GPIOA
#define RF_SW_CTRL2_Pin GPIO_PIN_13
#define RF_SW_CTRL2_GPIO_Port GPIOC

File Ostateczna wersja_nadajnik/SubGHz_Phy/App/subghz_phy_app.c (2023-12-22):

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

/* Includes ------------------------------------------------------------------*/
#include "platform.h"
#include "sys_app.h"
#include "subghz_phy_app.h"
#include "radio.h"

/* USER CODE BEGIN Includes */
#include "stm32_timer.h"
#include "stm32_seq.h"
#include "utilities_def.h"
#include "app_version.h"
#include "subghz_phy_version.h"
#include "main.h"
/* USER CODE END Includes */

/* External variables ---------------------------------------------------------*/
/* USER CODE BEGIN PTD */
typedef enum
{
  RX,
  RX_TIMEOUT,
  RX_ERROR,
  TX,
  TX_TIMEOUT,
} States_t;
/* USER CODE END PTD */

/* USER CODE BEGIN PD */
/* Configurations */
/*Timeout*/
#define RX_TIMEOUT_VALUE              3000
#define TX_TIMEOUT_VALUE              3000
/* PING string*/
#define PING "PING"

/* PONG string*/
#define ATAKUJ "ATAKUJ"
/*Size of the payload to be sent*/
/* Size must be greater of equal the PING and PONG*/
#define MAX_APP_BUFFER_SIZE          255
#if (PAYLOAD_LEN > MAX_APP_BUFFER_SIZE)
#error PAYLOAD_LEN must be less or equal than MAX_APP_BUFFER_SIZE
#endif /* (PAYLOAD_LEN > MAX_APP_BUFFER_SIZE) */
/* wait for remote to be in Rx, before sending a Tx frame*/
#define RX_TIME_MARGIN                200
/* Afc bandwidth in Hz */
#define FSK_AFC_BANDWIDTH             83333
/* LED blink Period*/
#define LED_PERIOD_MS                 200
/* USER CODE END PD */

/* Radio events function pointer */
static RadioEvents_t RadioEvents;

/* USER CODE BEGIN PV */

/*Ping Pong FSM states */
static States_t State = RX;
/* App Rx Buffer*/
static uint8_t BufferRx[MAX_APP_BUFFER_SIZE];
/* App Tx Buffer*/
static uint8_t BufferTx[MAX_APP_BUFFER_SIZE];
/* Last  Received Buffer Size*/
uint16_t RxBufferSize = 0;
/* Last  Received packer Rssi*/
int8_t RssiValue = 0;
/* Last  Received packer SNR (in Lora modulation)*/
int8_t SnrValue = 0;
/* Led Timers objects*/

/* device state. Master: true, Slave: false*/
bool isMaster = true;
/* random delay to make sure 2 devices will sync*/
/* the closest the random delays are, the longer it will
   take for the devices to sync when started simultaneously*/
static int32_t random_delay;
/* USER CODE END PV */

/*!
 * @brief Function to be executed on Radio Tx Done event
 */
static void OnTxDone(void);

/**
  * @brief Function to be executed on Radio Rx Done event
  * @param  payload ptr of buffer received
  * @param  size buffer size
  * @param  rssi
  * @param  LoraSnr_FskCfo
  */
static void OnRxDone(uint8_t *payload, uint16_t size, int16_t rssi, int8_t LoraSnr_FskCfo);

/**
  * @brief Function executed on Radio Tx Timeout event
  */
static void OnTxTimeout(void);

/**
  * @brief Function executed on Radio Rx Timeout event
  */
static void OnRxTimeout(void);

/**
  * @brief Function executed on Radio Rx Error event
  */
static void OnRxError(void);

/* USER CODE BEGIN PFP */
/**
  * @brief  Function executed on when led timer elapses
  * @param  context ptr of LED context
  */


/**
  * @brief PingPong state machine implementation
  */
static void PingPong_Process(void);
/* USER CODE END PFP */

/* Exported functions ---------------------------------------------------------*/
void SubghzApp_Init(void)
{
  /* USER CODE BEGIN SubghzApp_Init_1 */

  APP_LOG(TS_OFF, VLEVEL_M, "\n\rPING PONG\n\r");
  /* Get SubGHY_Phy APP version*/
  APP_LOG(TS_OFF, VLEVEL_M, "APPLICATION_VERSION: V%X.%X.%X\r\n",
          (uint8_t)(APP_VERSION_MAIN),
          (uint8_t)(APP_VERSION_SUB1),
          (uint8_t)(APP_VERSION_SUB2));

  /* Get MW SubGhz_Phy info */
  APP_LOG(TS_OFF, VLEVEL_M, "MW_RADIO_VERSION:    V%X.%X.%X\r\n",
          (uint8_t)(SUBGHZ_PHY_VERSION_MAIN),
          (uint8_t)(SUBGHZ_PHY_VERSION_SUB1),
          (uint8_t)(SUBGHZ_PHY_VERSION_SUB2));

  /* Led Timers*/

  /* USER CODE END SubghzApp_Init_1 */

  /* Radio initialization */
  RadioEvents.TxDone = OnTxDone;
  RadioEvents.RxDone = OnRxDone;
  RadioEvents.TxTimeout = OnTxTimeout;
  RadioEvents.RxTimeout = OnRxTimeout;
  RadioEvents.RxError = OnRxError;

  Radio.Init(&RadioEvents);

  /* USER CODE BEGIN SubghzApp_Init_2 */
  /*calculate random delay for synchronization*/
  random_delay = (Radio.Random()) >> 22; /*10bits random e.g. from 0 to 1023 ms*/

  /* Radio Set frequency */
  Radio.SetChannel(RF_FREQUENCY);

  /* Radio configuration */
#if ((USE_MODEM_LORA == 1) && (USE_MODEM_FSK == 0))
  APP_LOG(TS_OFF, VLEVEL_M, "---------------\n\r");
  APP_LOG(TS_OFF, VLEVEL_M, "LORA_MODULATION\n\r");
  APP_LOG(TS_OFF, VLEVEL_M, "LORA_FR=%d mHz\n\r", RF_FREQUENCY/1000000);
  APP_LOG(TS_OFF, VLEVEL_M, "LORA_PW=%d  dBm\n\r", TX_OUTPUT_POWER);
  APP_LOG(TS_OFF, VLEVEL_M, "LORA_BW=%d kHz\n\r", (1 << LORA_BANDWIDTH) * 125);
  APP_LOG(TS_OFF, VLEVEL_M, "LORA_SF=%d\n\r", LORA_SPREADING_FACTOR);

  Radio.SetTxConfig(MODEM_LORA, TX_OUTPUT_POWER, 0, LORA_BANDWIDTH,
                    LORA_SPREADING_FACTOR, LORA_CODINGRATE,
                    LORA_PREAMBLE_LENGTH, LORA_FIX_LENGTH_PAYLOAD_ON,
                    true, 0, 0, LORA_IQ_INVERSION_ON, TX_TIMEOUT_VALUE);


  Radio.SetMaxPayloadLength(MODEM_LORA, MAX_APP_BUFFER_SIZE);

#elif ((USE_MODEM_LORA == 0) && (USE_MODEM_FSK == 1))
  APP_LOG(TS_OFF, VLEVEL_M, "---------------\n\r");
  APP_LOG(TS_OFF, VLEVEL_M, "FSK_MODULATION\n\r");
  APP_LOG(TS_OFF, VLEVEL_M, "FSK_BW=%d Hz\n\r", FSK_BANDWIDTH);
  APP_LOG(TS_OFF, VLEVEL_M, "FSK_DR=%d bits/s\n\r", FSK_DATARATE);

  Radio.SetTxConfig(MODEM_FSK, TX_OUTPUT_POWER, FSK_FDEV, 0,
                    FSK_DATARATE, 0,
                    FSK_PREAMBLE_LENGTH, FSK_FIX_LENGTH_PAYLOAD_ON,
                    true, 0, 0, 0, TX_TIMEOUT_VALUE);

  Radio.SetRxConfig(MODEM_FSK, FSK_BANDWIDTH, FSK_DATARATE,
                    0, FSK_AFC_BANDWIDTH, FSK_PREAMBLE_LENGTH,
                    0, FSK_FIX_LENGTH_PAYLOAD_ON, 0, true,
                    0, 0, false, true);

  Radio.SetMaxPayloadLength(MODEM_FSK, MAX_APP_BUFFER_SIZE);

#else
#error "Please define a modulation in the subghz_phy_app.h file."
#endif /* USE_MODEM_LORA | USE_MODEM_FSK */

  /*fills tx buffer*/
  memset(BufferTx, 0x0, MAX_APP_BUFFER_SIZE);

  APP_LOG(TS_ON, VLEVEL_L, "rand=%d\n\r", random_delay);
  /*starts reception*/
  Radio.Rx(RX_TIMEOUT_VALUE + random_delay);

  /*register task to to be run in while(1) after Radio IT*/
  UTIL_SEQ_RegTask((1 << CFG_SEQ_Task_SubGHz_Phy_App_Process), UTIL_SEQ_RFU, PingPong_Process);
  /* USER CODE END SubghzApp_Init_2 */
}

static void OnTxDone(void)
{
  /* USER CODE BEGIN OnTxDone */
  APP_LOG(TS_ON, VLEVEL_L, "OnTxDone\n\r");
  /* Update the State of the FSM*/
  State = TX;
  /* Run PingPong process in background*/
  UTIL_SEQ_SetTask((1 << CFG_SEQ_Task_SubGHz_Phy_App_Process), CFG_SEQ_Prio_0);
  /* USER CODE END OnTxDone */
}
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

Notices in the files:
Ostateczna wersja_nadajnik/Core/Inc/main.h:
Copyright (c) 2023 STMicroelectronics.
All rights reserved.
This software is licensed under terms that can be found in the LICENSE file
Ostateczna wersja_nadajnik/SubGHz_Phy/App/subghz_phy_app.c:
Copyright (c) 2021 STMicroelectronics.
